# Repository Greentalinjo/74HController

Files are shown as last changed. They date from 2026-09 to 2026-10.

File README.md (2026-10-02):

<p align="center">
  74HC-ontroller logo
</p>

# 74HC-ontroller

**A game controller built entirely from discrete 74HC logic.** Eight keys, a
diode ROM for a character table, and a real 8-N-1 serial frame out of an RJ45
console port — no microcontroller, no FPGA, no firmware, nothing programmable
anywhere on the board.

## Preface

This project started as an idea for a novel, old-school game controller to
plug into a MikroTik RB4011 that I own and am turning into a gaming console.
The RB4011 already has what a console needs to hear a controller — a serial
console port on an RJ45 jack — so the controller only has to do one thing:
turn a button press into a character on that line.

The twist is *how*. Instead of a microcontroller running a few lines of code,
every step — watching the buttons, noticing a change, looking up the
character, and shifting it out bit by bit at 115200 baud — is done by
sixteen logic chips from the 74HC family, the kind you would find in a 1980s
computer, plus one RS-232 line driver. Change the character a button sends by
moving a diode.

| At a glance | |
|---|---|
| Keys | 5-way navigation cluster + 3 Cherry MX switches |
| Output | 8-N-1 serial, 115200 baud by default, as RS-232 on an RJ45 (Cisco console pinout) or 3.3 V TTL on a header |
| Logic | 16 × 74HC-series ICs + a MAX3232 RS-232 transceiver |
| Key map | an 8 × 7 diode ROM — 56 positions, a diode wherever a bit is 1 |
| Power | one AA cell, boosted to 3.3 V; ~1.3 mA, roughly four weeks of continuous use |
| Board | 150 × 60 mm, 6 layers, 1.6 mm |
| Case | 3D-printed, three colours, sliding battery door |

---

## Contents

1. [How it works — the big picture](#1-how-it-works--the-big-picture)
2. [The pipeline, stage by stage](#2-the-pipeline-stage-by-stage)
3. [Putting it together: the life of a key press](#3-putting-it-together-the-life-of-a-key-press)
4. [What you can configure](#4-what-you-can-configure)
5. [Using it with a MikroTik console](#5-using-it-with-a-mikrotik-console)
6. [The hardware](#6-the-hardware)
7. [The case](#7-the-case)
8. [Building one](#8-building-one)
9. [Repository layout](#9-repository-layout)

---

## 1. How it works — the big picture

A microcontroller would handle a key press with a loop and an interrupt. This
board does the same job as a small **pipeline of hardware stages**, each on
its own schematic sheet, each handing a signal to the next:

```mermaid
flowchart LR
    subgraph clock["Power, clock, reset"]
        P["AA cell → boost → 3.3 V"]
        C["crystal → 74HC4060 → baud tap<br/>CLK / nCLK"]
        R["power-on reset<br/>POR_n"]
    end

    K["8 keys<br/>RC + Schmitt debounce"] --> L["74HC151<br/>LIVE key"]
    S["74HC161<br/>scan counter"] -- "address" --> L
    S -- "address" --> M["74HC259<br/>state memory"]
    M --> T["74HC151<br/>STORED key"]
    S -- "address" --> T
    L --> X["74HC86<br/>DIFF = LIVE xor STORED"]
    T --> X
    X --> B["74HC74<br/>BUSY"]
    B -- "freeze" --> S
    B --> Q["74HC161 + 74HC138<br/>frame sequencer"]
    Q -- "state 10: store" --> M
    S -- "address" --> D["74HC238 + diode ROM<br/>the character"]
    D --> SR["2 × 74HC165<br/>shift register"]
    SR --> G["74HC32<br/>output gate"]
    G --> O["JP4: TTL header<br/>or MAX3232 → RJ45"]
```

The idea in one paragraph: a counter **scans** the eight keys one at a time,
comparing each key's **live** state with the state the board **remembers**.
When they differ, a key has changed. The board then **freezes the scan** on
that key, uses the key's number to select a row of the **diode ROM** — which
presents that key's character — **shifts** the character out as a serial
frame, **stores** the key's new state so the difference disappears, and
**resumes** scanning. Everything is clocked by the baud-rate clock, so the
whole machine runs in lock-step with the serial line.

---

## 2. The pipeline, stage by stage

The schematic is split into seven sheets, in the order a signal travels
through them. A PDF of the whole schematic is in
[`docs/schematic.pdf`](docs/schematic.pdf).

### Stage 1 — Power, clock and reset *(sheet: Power, Clock, Reset)*

Everything else depends on three things from this sheet.

**Power.** One AA cell goes through the power switch (SW10) into an
**ME2108A33 boost converter** (U18, with L1, D3 and C1), which makes the
board's single **3.3 V** rail. It starts from a 0.9 V cell and keeps
regulating down to 0.45 V, so the battery is used to the end. JP1 can instead
take power from the TTL header. D1 is the power LED.

**Clock.** A **3.6864 MHz crystal** drives the oscillator inside a
**74HC4060** (U1), which also divides the frequency by powers of two. Jumper
**JP2** picks one of those outputs as the bit clock, `CLK` — by default
3.6864 MHz ÷ 32 = exactly **115200 Hz**, one tick per serial bit. A Schmitt
inverter makes `nCLK`, its opposite edge, which the control logic uses.

**Reset.** An RC network (R6, C5) and two Schmitt inverters hold `POR_n` low
for about 87 ms at switch-on, which clears the state memory, the scanner and
the BUSY flag — so the controller never sends a burst of junk characters when
it powers up. SW9 is a manual reset button.

### Stage 2 — Keys and debounce *(sheet: Keys and Debounce)*

Each of the eight keys has its own complete **debounce cell**: a 10 kΩ
pull-up, a 1 kΩ series resistor, a 1 µF capacitor to ground and a **74HC14
Schmitt-trigger** inverter.

```
+3V3 ──[10k]──┬──[1k]── switch ── GND
              │
             1µF          ──► 74HC14 ──► KEYn  (high while pressed)
              │
             GND
```

The cell is deliberately **asymmetric**: pressing discharges the capacitor
through 1 kΩ (a ~1.7 ms response), releasing recharges it through 10 kΩ
(~7.4 ms). The slow edges swallow contact bounce, and the Schmitt trigger
turns the slow analogue ramp into one clean logic edge.

The keys are **KEY0–KEY4**: the five directions of an SJMS 5-way navigation
cluster (SW1, one package) — **KEY5–KEY7**: three Cherry MX switches (SW6–SW8).

### Stage 3 — Scanner and memory *(sheet: Scanner and Memory)*

This stage decides *whether* anything needs sending.

* A **74HC161 counter** (U4) steps a 3-bit address, `ADDR0–2`, through the
  eight keys, one key per clock tick. A full sweep takes eight bit times.
* A **74HC151 multiplexer** (U5) reads the addressed key's live state: `LIVE`.
* A **74HC259 addressable latch** (U6) is the board's memory — eight bits
  holding the last state that was *reported* for each key.
* A second **74HC151** (U7) reads the remembered state of the same key:
  `STORED`. (The '259 has no read-back port of its own, so this second
  multiplexer is essential.)
* A **74HC86 XOR** gate compares the two: `DIFF = LIVE xor STORED`.

`DIFF` goes high exactly when the key under the scanner has changed since it
was last reported. That is the only event this whole machine reacts to.

### Stage 4 — Transmit sequencer *(sheet: Transmit Sequencer)*

This stage runs a transmission once `DIFF` says there is something to send.

* **`BUSY`** — a 74HC74 flip-flop (U9A) captures `DIFF` on the `nCLK` edge.
  While `BUSY` is high, the scan counter is **frozen** through its count
  enables. The clock itself is never gated, so there are no glitches.
* A second **74HC161** (U10) counts the bit times of the frame, and a
  **74HC138** decoder (U11) picks out two moments from that count:
  * **State 10** — the frame has finished, so it pulses the 74HC259's write
    enable. The key's new state is stored, `DIFF` falls, and on the next edge
    `BUSY` clears itself and the scanner moves on.
  * **State 11** — a lock-up escape. If `DIFF` somehow failed to clear, the
    second flip-flop (U9B) forces `BUSY` off, so the controller can never
    freeze for good.

The whole event takes **11 bit times**: 10 for the frame, 1 to store and
resume. That's about 95 µs at 115200 baud.

### Stage 5 — ASCII diode ROM *(sheet: ASCII Diode ROM)*

This stage decides *what* gets sent. It is a real read-only memory, built
from diodes:

* A **74HC238 decoder** (U14) takes the frozen key address and drives exactly
  one of eight **rows** high — one row per key.
* Seven **columns** run across the rows, one per bit of the ASCII code
  (b0–b6), each held low by a 15 kΩ pull-down (R30–R36).
* Where a bit should be 1, a **diode** connects that key's row to that bit's
  column (anode to the row, cathode to the column). Driving the row pulls
  those columns high; the rest stay low.

Of the 56 positions (8 keys × 7 bits), **27 are fitted** for the default key
map. The decoder is only enabled while `DIFF` is high, so the ROM draws
nothing at rest.

### Stage 6 — UART shift register *(sheet: UART Shift Register)*

Two **74HC165 shift registers** (U15, U16) are chained into a 16-bit
register that holds the whole frame:

| Frame bit | Comes from |
|---|---|
| start (0) | tied to ground |
| b0 … b6 | the ROM columns |
| bit 7 | make/break flag (see §4) |
| stop (1) | tied to 3.3 V |
| idle (1s) | tied to 3.3 V |

While the board is idle, `BUSY` holds the registers in **parallel load**, so
the start bit is already waiting on the output. The instant `BUSY` rises they
start shifting — one bit per `nCLK` — which produces the serial frame
directly, least-significant bit first.

A **74HC32 OR gate** (U13) then forms the final line:
`TX = shift register OR not-BUSY OR SUPPRESS`. `not-BUSY` parks the line high
(idle) between frames, and `SUPPRESS` blanks a key-*release* frame when break
codes are turned off.

### Stage 7 — Output *(sheet: Output Stage)*

The finished 3.3 V serial line goes to **JP4**, which sends it one of two ways:

* **RS-232** — through a **MAX3232** (U17) to the **RJ45** console jack, using
  the Cisco console pinout that MikroTik and most network gear use.
* **3.3 V TTL** — to the 4-pin header **J3**, for a USB-serial adapter or
  another board.

The MAX3232's spare receiver also converts the *other* direction: whatever
the connected device prints on its console comes back as 3.3 V TTL on J3 pin
3, so you can watch the console while the controller drives it.

---

## 3. Putting it together: the life of a key press

Everything is timed in **bit times** (one `CLK` period: 8.7 µs at 115200
baud). The control logic acts on `nCLK`, half a bit away from the scanner's
`CLK`, so the scan address is always settled before anything reads it.

| When | What happens |
|---|---|
| — | You press a key. The debounce cell settles, and `KEYn` goes high about 1.7 ms later. |
| within 8 bit times | The scanner reaches that key. `LIVE` = 1, `STORED` = 0, so **`DIFF` = 1**. |
| f0 | `BUSY` rises on `nCLK`. The scanner **freezes**, the ROM row for this key is driven, and the shift registers start sending — the **start bit** is already on the line. |
| f1 – f7 | ASCII bits **b0 … b6**, straight from the diode ROM. |
| f8 | **bit 7** (0 unless make/break codes are on). |
| f9 | **stop bit**. |
| f10 | Sequencer state 10: the new key state is **written into memory**. `DIFF` falls. |
| f11 | `BUSY` clears itself. The scanner **resumes**. |

Releasing the key is the same event in reverse: the key now differs from
memory again, so another frame is sent, or quietly suppressed if break codes
are off.

Because each change is handled on its own sweep, pressing all eight keys at
once produces eight clean frames back to back (8.8 ms at 9600 baud, under
1 ms at 115200). Nothing is lost and nothing is merged, since only one key
can be transmitting at a time.

---

## 4. What you can configure

Everything is set with jumpers, solder bridges and diodes. There's no
firmware to reflash.

### Jumpers at a glance

| Ref | What it sets | Options | Default |
|---|---|---|---|
| **JP1** | Power source | 1-2 AA cell via the boost converter · 2-3 from TTL header J3 pin 4 | 1-2 |
| **JP2** | Baud rate | one shunt across one of seven columns (below) | column 2 = 115200 |
| **JP3** | Break codes | open = press only · fitted = press *and* release | open |
| **JP4** | Output | 1-2 RS-232 on the RJ45 · 2-3 3.3 V TTL on J3 | 2-3 |
| **JP5** | Both outputs | solder bridge: drive RS-232 *and* TTL at once | open |
| **JP6 / JP7** | RJ45 cable type | both 2-3 straight patch cable · both 1-2 rollover console cable | 2-3 |
| **JP8 / JP9** | Handshake | solder bridges that assert DSR / CTS, for devices that insist | open |

### Baud rate — JP2 and the crystal

JP2 picks a divider tap from the 74HC4060. Its seven columns follow the
chip's pin order, **not** baud order. That keeps the wiring uncrossed, and a
table on sheet 2 of the schematic maps them.

| JP2 column | 1 | 2 | 3 | 4 | 5 | 6 | 7 |
|---|---|---|---|---|---|---|---|
| '4060 tap | Q6 ÷64 | Q5 ÷32 | Q7 ÷128 | Q4 ÷16 | Q10 ÷1024 | Q8 ÷256 | Q9 ÷512 |
| **3.6864 MHz** (fitted) | 57600 | **115200** | 28800 | 230400 | 3600 | 14400 | 7200 |
| 4.9152 MHz | 76800 | 153600 | 38400 | 307200 | 4800 | 19200 | **9600** |

115200 and 9600 differ by a factor of 12, not a power of two, so no single
crystal reaches both. For a 9600-baud controller, fit a 4.9152 MHz crystal
and use column 7.

### The key map — moving diodes

Each key sends the 7-bit ASCII code wired into its row of the ROM. The diode
for **key *k*, bit *b*** is **D2*kb***. For example, D245 is key 4, bit 5.
Fit a diode wherever the bit should be 1.

| Key | Button | Sends | Code | Diodes fitted |
|---|---|---|---|---|
| 0 | nav centre / OK | Enter (CR) | 0x0D | D200 D202 D203 |
| 1 | nav up | Tab | 0x09 | D210 D213 |
| 2 | nav down | Esc | 0x1B | D220 D221 D223 D224 |
| 3 | nav left | Ctrl-C | 0x03 | D230 D231 |
| 4 | nav right | `/` | 0x2F | D240 D241 D242 D243 D245 |
| 5 | MX 1 | `?` | 0x3F | D250 D251 D252 D253 D254 D255 |
| 6 | MX 2 | Space | 0x20 | D265 |
| 7 | MX 3 | `q` | 0x71 | D270 D274 D275 D276 |

The silkscreen labels the grid like a table, since 56 designators would not
fit. Across the top is `D20 21 22 … 27`, one label per key column. Down the
right side is `0`–`6`, one per bit, next to that bit's pull-down R30–R36. A
diode's designator is the label above it followed by the digit beside it.

### Press-only or make/break — JP3

* **Open (default):** a key sends its character when pressed and nothing on
  release. This is plain typing, the right choice for a console.
* **Fitted:** a press sends `0x80 | code` and a release sends `code`. Bit 7
  carries the key's state, which gives a game true key-down/key-up events.

### Output — JP4, JP5, JP6/JP7, JP8/JP9

* **JP4** chooses RS-232 on the RJ45 or 3.3 V TTL on J3. The unused output is
  held at its idle level, not left floating.
* **JP5** drives both outputs at once.
* **JP6/JP7** move the transmit and receive lines between RJ45 pins 3 and 6,
  so both a straight patch cable and a rollover console cable work. Always
  move them together.
* **JP8/JP9** assert DSR and CTS from a spare driver. RouterOS doesn't need
  them.

**J3 (TTL header):** 1 GND · 2 TXD out · 3 RXD (the far end's console, as
3.3 V TTL) · 4 +3.3 V, in or out depending on JP1.

### Other options

* **Power LED:** leave D1 and R3 off to save 0.28 mA, about a quarter of the
  idle current.
* **R53** stays unfitted. It belonged to a 5 V version of the design and
  would now pull the TTL output below a 3.3 V input's threshold.

---

## 5. Using it with a MikroTik console

1. Set **JP4 to 1-2** (RS-232), and leave JP6/JP7 on 2-3.
2. Connect the controller's RJ45 to the router's **Serial** console port with
   an ordinary straight Ethernet patch cable.
3. The console runs at **115200 8-N-1**, which is JP2's default. RouterBOOT's
   console rate can't be changed, which is why the controller runs at
   115200 rather than 9600.
4. Switch on. Every key press arrives on the console as a plain keystroke,
   ready for whatever is reading it.

For a PC instead, set JP4 to 2-3 and plug a 3.3 V USB-serial adapter into
J3.

---

## 6. The hardware

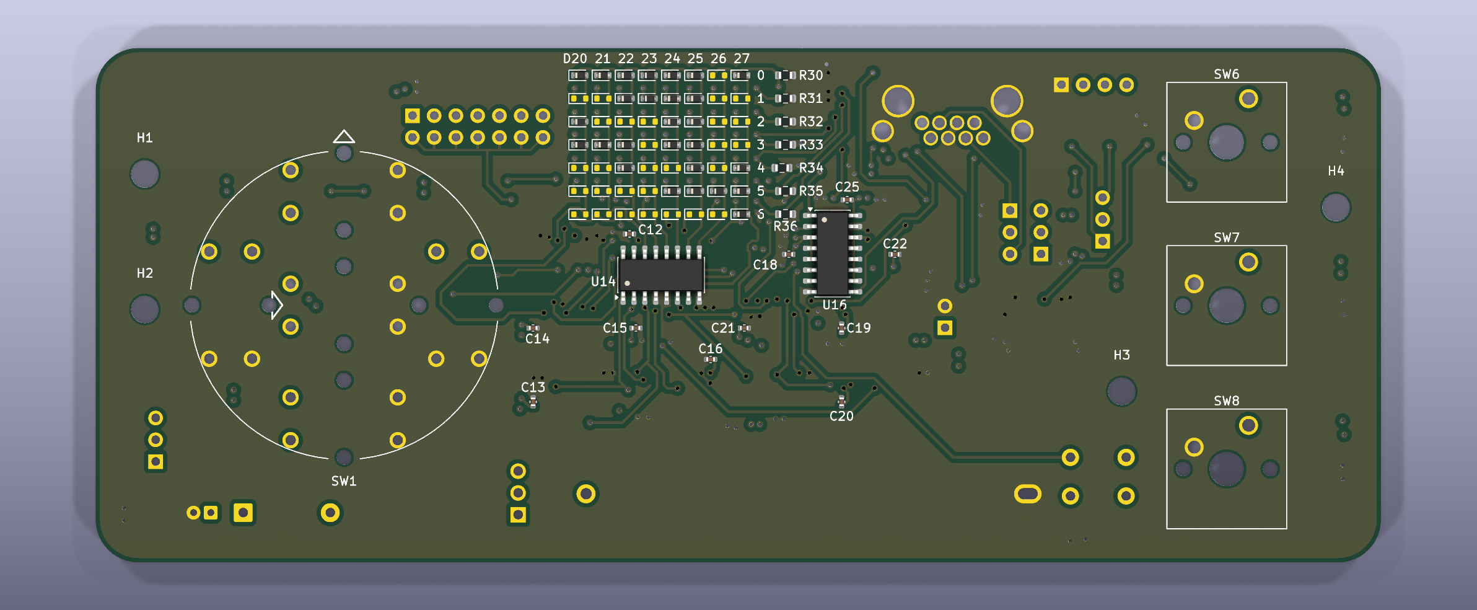
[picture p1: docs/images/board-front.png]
Board front

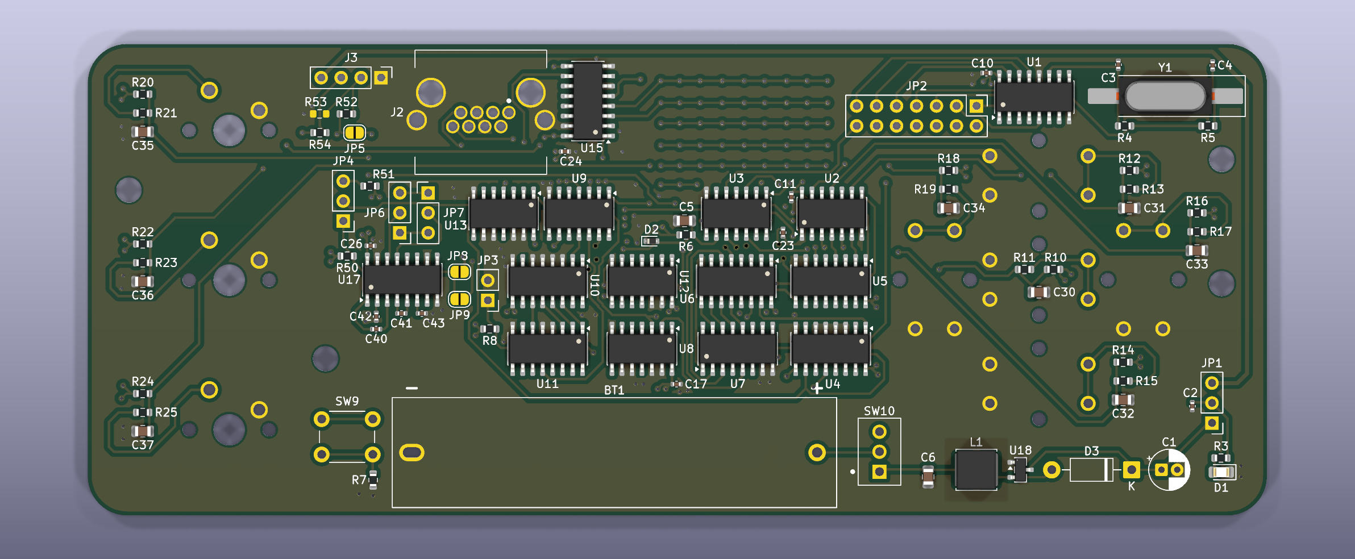
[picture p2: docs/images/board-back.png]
Board back


* **150 × 60 mm, 6-layer, 1.6 mm.** Signals run on the outer layers. Ground
  is poured on the top, bottom and three inner layers, and the 3.3 V supply
  has its own inner plane.
* **Front:** the navigation cluster, the three MX switches, the diode ROM and
  its decoder and pull-downs, one of the shift registers and some decoupling.
* **Back:** the rest of the logic, the RJ45, the TTL and jumper headers, the
  power switch, the reset button and the AA holder.
* **Parts:** all logic in SOIC. Passives are 0603/0402, with 0805 for the 1 µF
  debounce capacitors, and the ROM diodes are SOD-523. Through-hole parts are
  used only where needed: switches, connectors, headers, the AA holder, C1
  and D3.
* **Four M3 mounting holes** (H1–H4) take the case screws.

Three parts have requirements the footprint alone doesn't capture:

* **C30–C37 and C5 (1 µF) must be 0805 X7R.** A 1 µF 0402 part loses so much
  capacitance under DC bias that the debounce timing guarantee breaks at
  9600 baud.
* **C3/C4 (30 pF crystal load) must be C0G/NP0**, to keep the oscillator
  stable and starting reliably.
* **U17 must be a MAX3232** (or MAX232A/SP3232), not a plain MAX232, which
  needs 1 µF pump capacitors. The logic must be **74HC**, not 74HCT or 74LS.

### How it was checked

Before any copper was ordered, the design's netlist was run in a purpose-built
logic simulator that models every IC against its datasheet truth table.
Switches were driven through the real RC debounce values, and the serial
output was decoded like a real UART receiver. The runs covered:
* 108 scenarios, including every key, eight keys at once, bounce, make/break,
  both outputs and a deliberate lock-up;
* 1,268 randomised and exhaustive assertions, including all 255 key
  combinations;
* a DC noise-margin check of every logic level at 3.3 V.

The simulator isn't part of this repository. The schematic passes KiCad ERC
with no errors, and the board passes DRC and matches the schematic.

---

## 7. The case

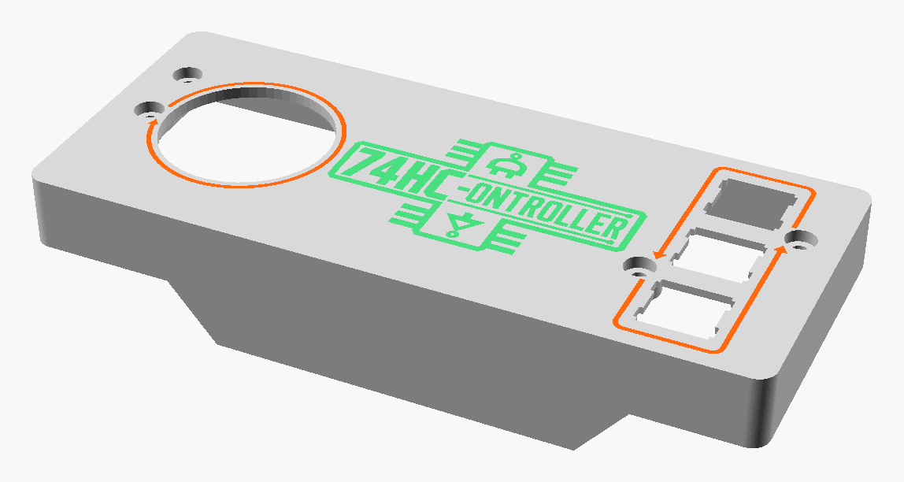
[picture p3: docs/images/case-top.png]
Case top, with the three-colour inlay


A three-piece 3D-printed enclosure, ready to slice, in [`case/`](case/):

| File | Part | Print |
|---|---|---|
| `top_with_trim.3mf` | top shell, holding the switches | three colours: plate, trim and logo inlays. Print plate side down, no supports |
| `bottom.3mf` | bottom shell | print on its raised hump. Support only the flat undersides (grid supports, build plate only, 2–3 interface layers, a brim) |
| `door.3mf` | battery door | outer face down, no supports |

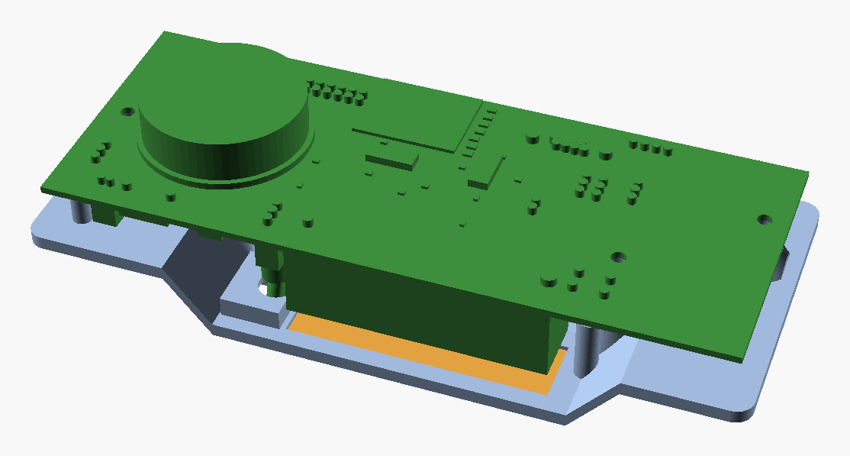
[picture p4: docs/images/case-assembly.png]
Opened assembly


The case is shaped to be held in both hands from the ends. The bottom steps
down only where the tall parts are (the battery, power switch and RJ45) and
slopes up everywhere else. It has:
* windows over every jumper header;
* a pinhole for the reset button;
* a pocket for the power switch lever;
* a small light hole for the power LED;
* an RJ45 opening in the top wall.

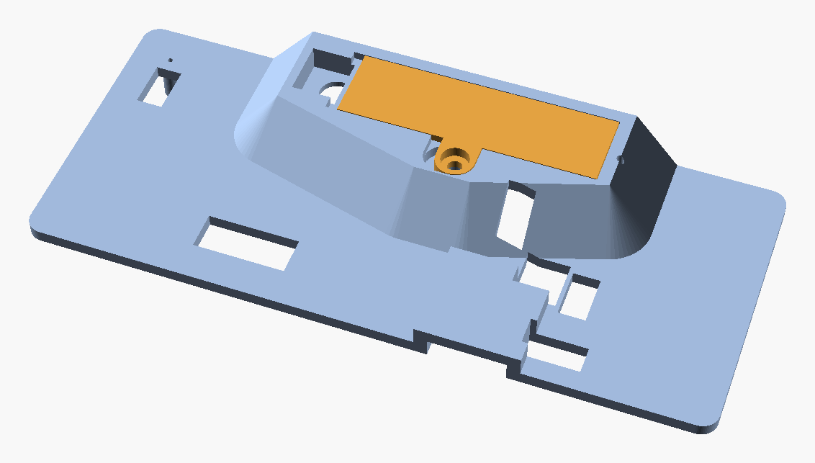
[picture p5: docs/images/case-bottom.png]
Bottom shell


**Hardware:** five **M3 × 8 pan-head screws** and five **M3 heat-set
inserts**, which go in 4.2 mm holes up to 8 mm deep.

**Assembly:**
1. Clip the switches into the top plate and solder the PCB to them.
2. Press heat-set inserts into the tops of the bottom shell's four posts, and
   the fifth into the battery door's screw boss, from underneath.
3. Close the bottom and drive four screws down through the counterbored holes
   in the top, so the heads sit flush, through the PCB and into the inserts.
4. Drop the battery door into its seat, slide it right so its tongues go
   under the lip, and fix it with the fifth screw.

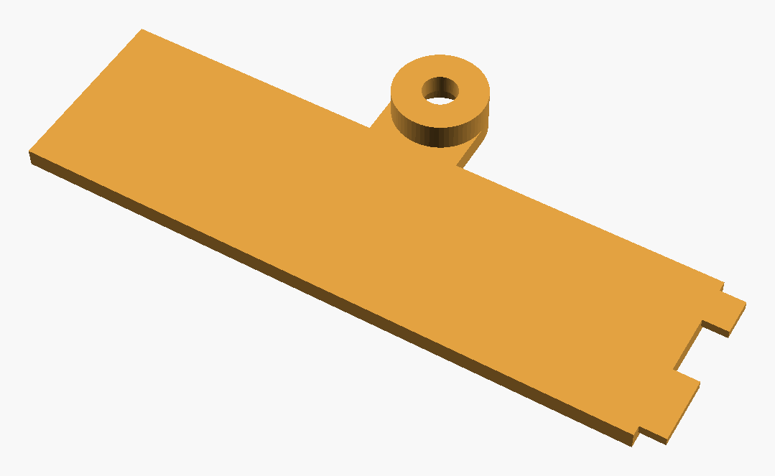
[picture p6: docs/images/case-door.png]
Battery door


---

## 8. Building one

1. **The PCB.** Open `kicad/logic-macropad.kicad_pro` in **KiCad 10** or newer
   and plot gerbers and drill files. The project is self-contained, with its
   own symbol and footprint libraries. Order 6 layers, 1.6 mm, FR-4. Nothing
   on the board is impedance-sensitive, so any standard stackup works.
2. **The parts.** Every symbol carries its specification and an example part
   number in its fields. *Tools → Generate BOM* in the schematic editor, or
   `kicad-cli sch export bom`, lists them. The 29 unused ROM positions and
   R53 are marked *do not populate*.
3. **Assembly.** Everything is hand-solderable, but the SOD-523 ROM diodes are
   small. Fit only the diodes for your key map (§4). Set the jumpers, fit an
   AA cell, and switch on.

---

## 9. Repository layout

```
kicad/                          the KiCad 10 project
  logic-macropad.kicad_pro        project, design rules
  logic-macropad.kicad_sch        root sheet: block diagram, the seven stages
  01_power_clock.kicad_sch        stage 1  power, clock, reset
  02_keys_debounce.kicad_sch      stage 2  keys and debounce
  03_scanner.kicad_sch            stage 3  scanner and memory
  04_sequencer.kicad_sch          stage 4  transmit sequencer
  05_ascii_rom.kicad_sch          stage 5  ASCII diode ROM
  06_uart_tx.kicad_sch            stage 6  UART shift register
  07_output.kicad_sch             stage 7  output stage
  logic-macropad.kicad_pcb        the 6-layer board
  lib/, logic-macropad.pretty/    project symbols and footprints
case/                           print-ready 3MF files for the enclosure
docs/
  schematic.pdf                   the full schematic
  images/                         renders used in this README
```

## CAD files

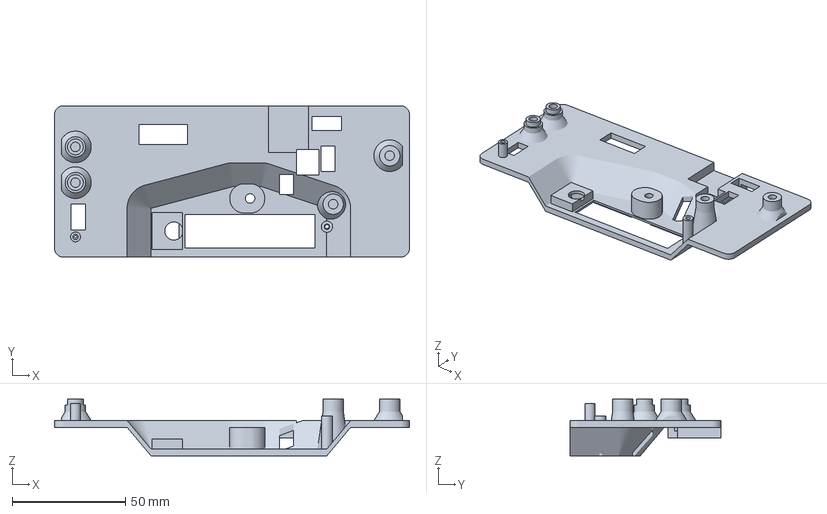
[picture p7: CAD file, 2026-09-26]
case/bottom.3mf
157.0 x 67.0 x 25.1 mm

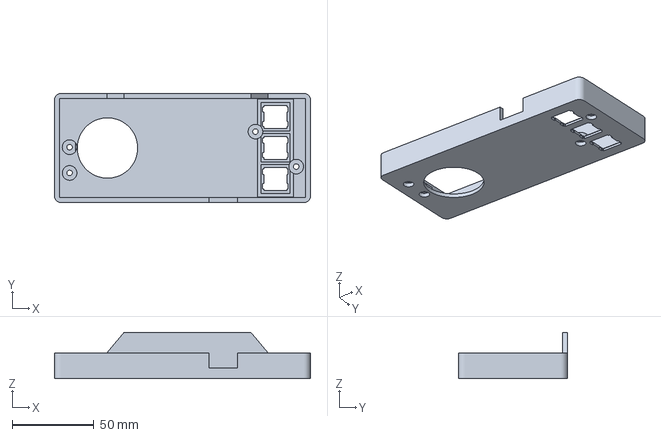
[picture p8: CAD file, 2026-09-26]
case/top_with_trim.3mf
157.0 x 67.0 x 28.5 mm

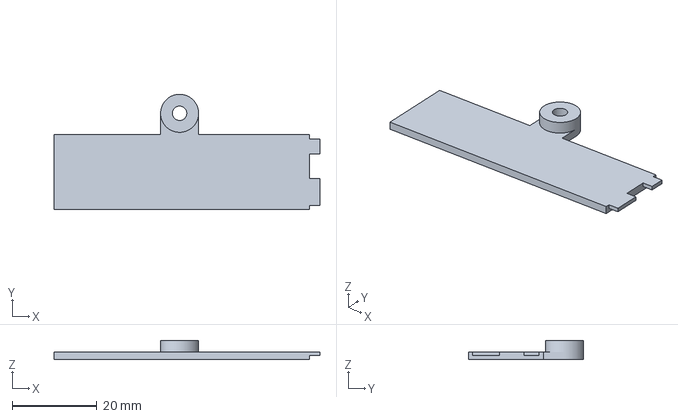
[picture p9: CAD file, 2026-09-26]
case/door.3mf
62.9 x 27.3 x 4.50 mm

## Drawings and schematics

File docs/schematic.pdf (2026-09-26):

1 | 2 | 3 | 4 | 5 | 6 | 7 | 8

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
Size: A3 | Rev: A | F Date: 2026-09-04
KiCad E.D.A. 10.0.1 | Id: 1/8

## Title: Logic Macropad - Root / block diagram

File: logic-macropad.kicad_sch

Sheet: /

8-key macropad, 74HC logic only, no MCU/FPGA

Selectable TTL UART or RS-232 output

Output Stage

File: 07_output.kicad_sch

Keys and Debounce

File: 02_keys_debounce.kicad_sch

ASCII Diode ROM

File: 05_ascii_rom.kicad_sch

Power, Clock, Reset

File: 01_power_clock.kicad_sch

UART Shift Register

File: 06_uart_tx.kicad_sch

Scanner and Memory

File: 03_scanner.kicad_sch

Transmit Sequencer

File: 04_sequencer.kicad_sch

#FLG02 PWR_FLAG

#FLG01 PWR_FLAG +3V3 | GND

PWR_FLAGs: tell ERC that +3V3 / GND are driven.

8-key keypad that emits a real 8-N-1 serial frame per key event, built only from 74HC glue logic and a diode ROM. No MCU, no FPGA, no firmware, no programmable part of any kind.

### PRINCIPLE OF OPERATION

A 74HC161 sweeps a 3-bit address across the 8 keys at the bit clock, so every key is sampled 1/8 of the baud rate (1200 Hz at 9600 baud).

### 74HC151 #1 reads the LIVE debounced key at that address; 74HC151 #2

reads the STORED state of the same address out of a 74HC259 latch.

### A 74HC86 XORs them. A difference sets the BUSY flip-flop on the

FALLING clock edge, which freezes the scan counter through its synchronous count-enables (CEP/CET) - the clock itself is never gated, so no runt pulses are possible.

While BUSY, the frozen address selects one row of a 74HC238 +
diode ROM, which presents 7 ASCII bits to a pair of 74HC165s.
The shift registers emit start / b0..b6 / make-break / stop over
the next 10 bit times. A second 74HC161 + 74HC138 count the frame,
write the new key state into the 74HC259 at state 10, and release BUSY one bit later. Scanning resumes; N-key rollover falls out for free because each pending change is serviced on a later sweep.
OUTPUT | JP4 selects 3.3V TTL UART or RS-232 (MAX3232 -> RJ45).
BAUD | JP2 taps the 74HC4060 divider; see sheet 2 for the table.
ASCII MAP | Set by which diodes are fitted; see sheet 6.

# DISCRETE LOGIC SERIAL MACROPAD

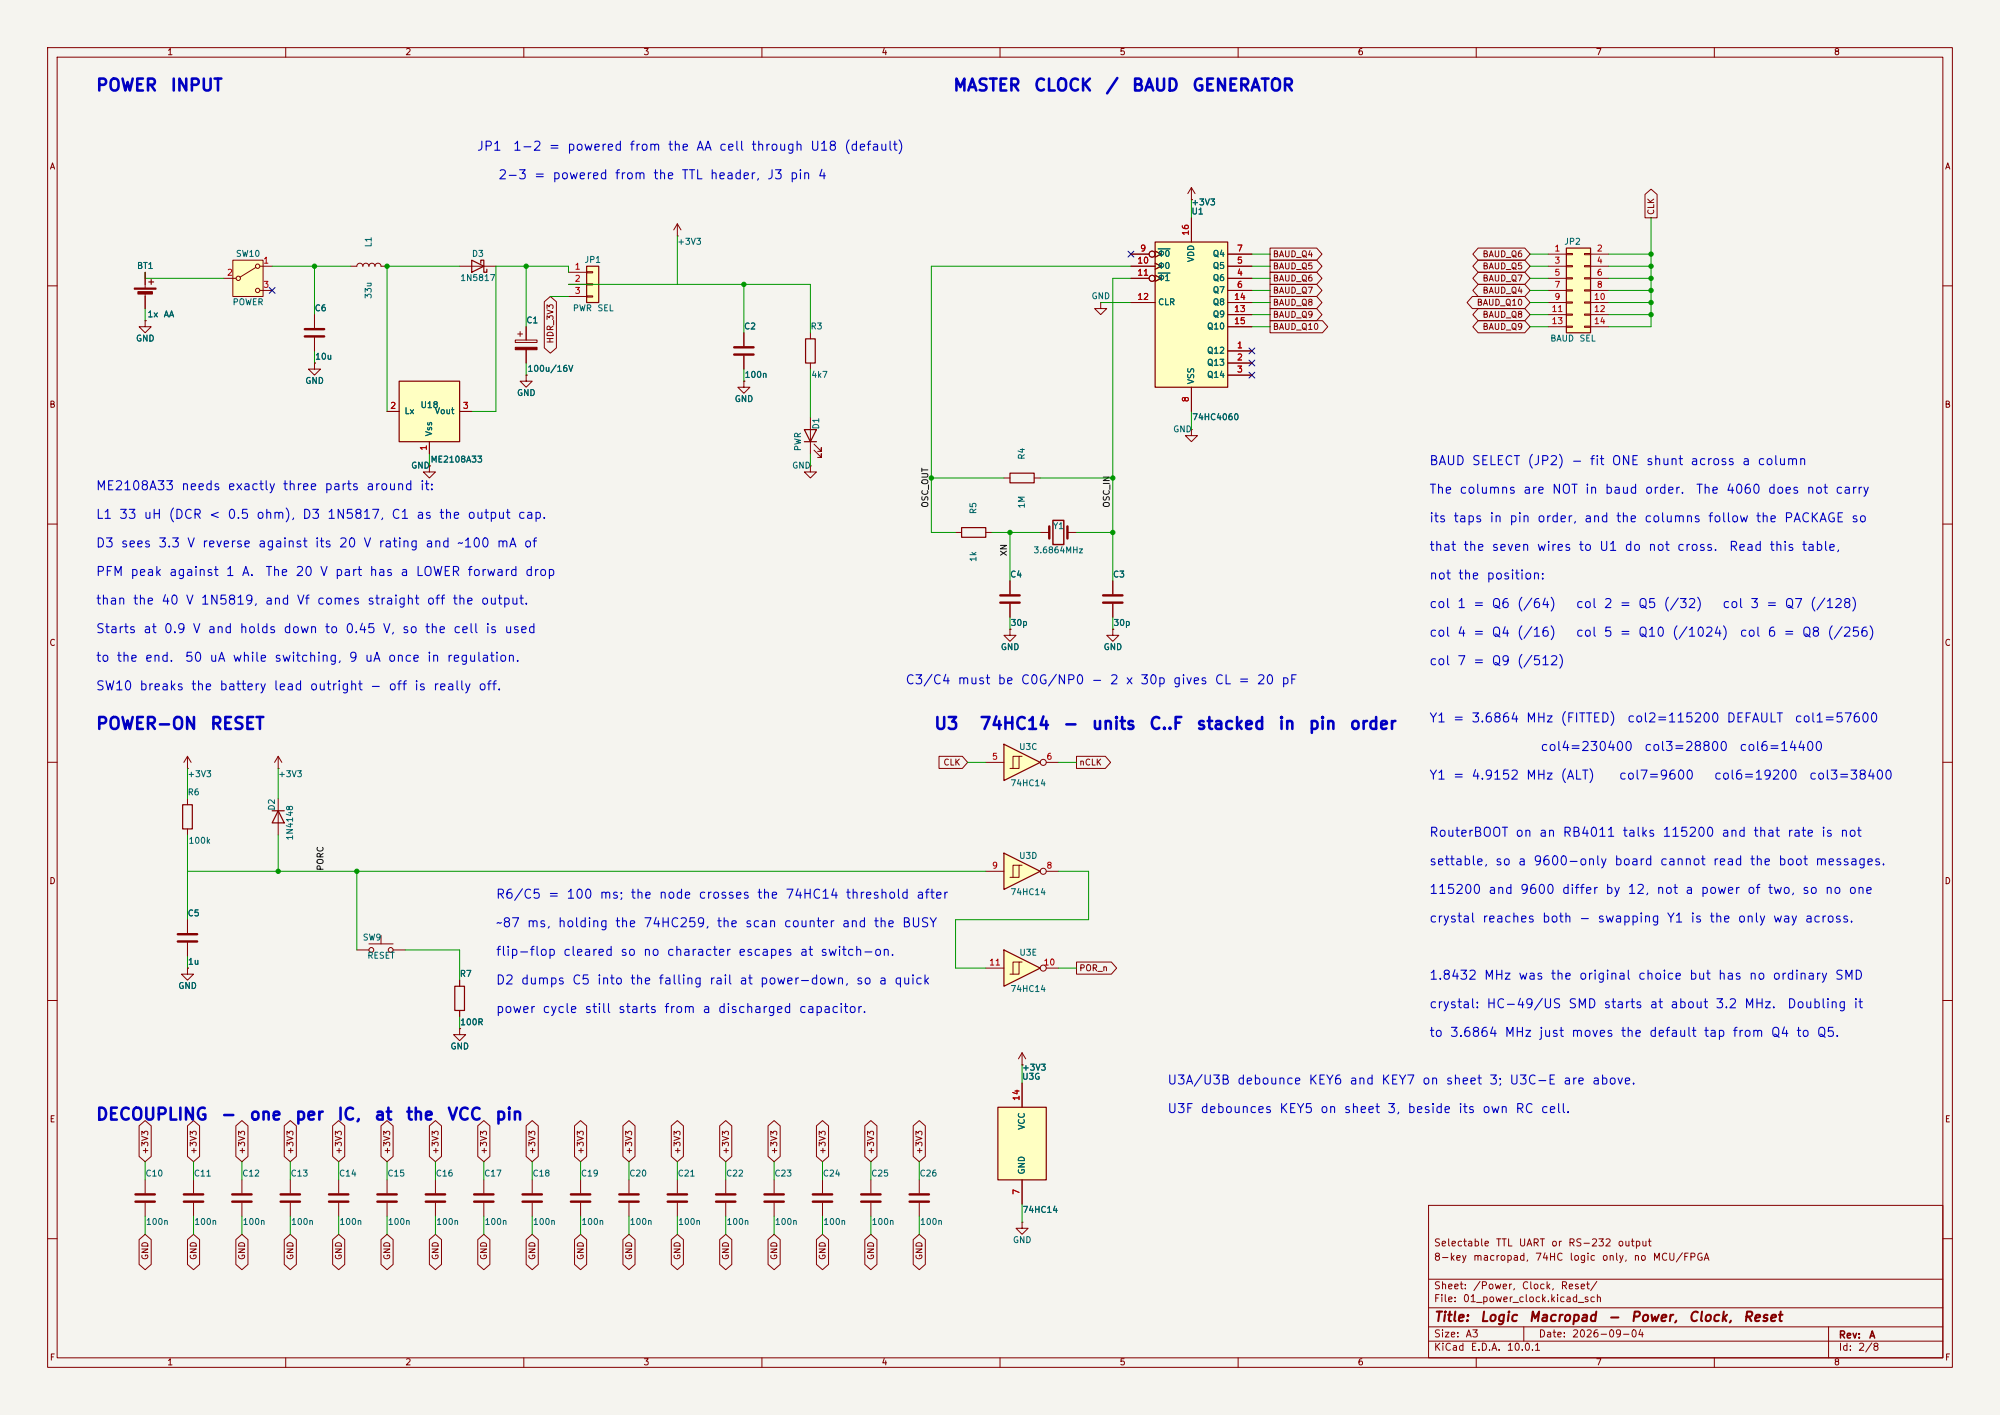
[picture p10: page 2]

MASTER CLOCK / BAUD GENERATOR

JP1 1-2 = powered from the AA cell through U18 (default)

2-3 = powered from the TTL header, J3 pin 4

BAUD SELECT (JP2) - fit ONE shunt across a column

L1 33 uH (DCR < 0.5 ohm), D3 1N5817, C1 as the output cap.
its taps in pin order, and the columns follow the PACKAGE so Starts at 0.9 V and holds down to 0.45 V, so the cell is used

D3 sees 3.3 V reverse against its 20 V rating and ~100 mA of

that the seven wires to U1 do not cross. Read this table,

PFM peak against 1 A. The 20 V part has a LOWER forward drop

than the 40 V 1N5819, and Vf comes straight off the output.

to the end. 50 uA while switching, 9 uA once in regulation.

C3/C4 must be C0G/NP0 - 2 x 30p gives CL = 20 pF

SW10 breaks the battery lead outright - off is really off.

U3 74HC14 - units C..F stacked in pin order

RouterBOOT on an RB4011 talks 115200 and that rate is not

settable, so a 9600-only board cannot read the boot messages.

R6/C5 = 100 ms; the node crosses the 74HC14 threshold after

115200 and 9600 differ by 12, not a power of two, so no one

~87 ms, holding the 74HC259, the scan counter and the BUSY

crystal reaches both - swapping Y1 is the only way across. 1.8432 MHz was the original choice but has no ordinary SMD

flip-flop cleared so no character escapes at switch-on.

D2 dumps C5 into the falling rail at power-down, so a quick

crystal: HC-49/US SMD starts at about 3.2 MHz. Doubling it

power cycle still starts from a discharged capacitor.

to 3.6864 MHz just moves the default tap from Q4 to Q5.

U3A/U3B debounce KEY6 and KEY7 on sheet 3; U3C-E are above.

8-key macropad, 74HC logic only, no MCU/FPGA

Sheet: /Power, Clock, Reset/
File: 01_power_clock.kicad_sch
Title: Logic Macropad - Power, Clock, Reset

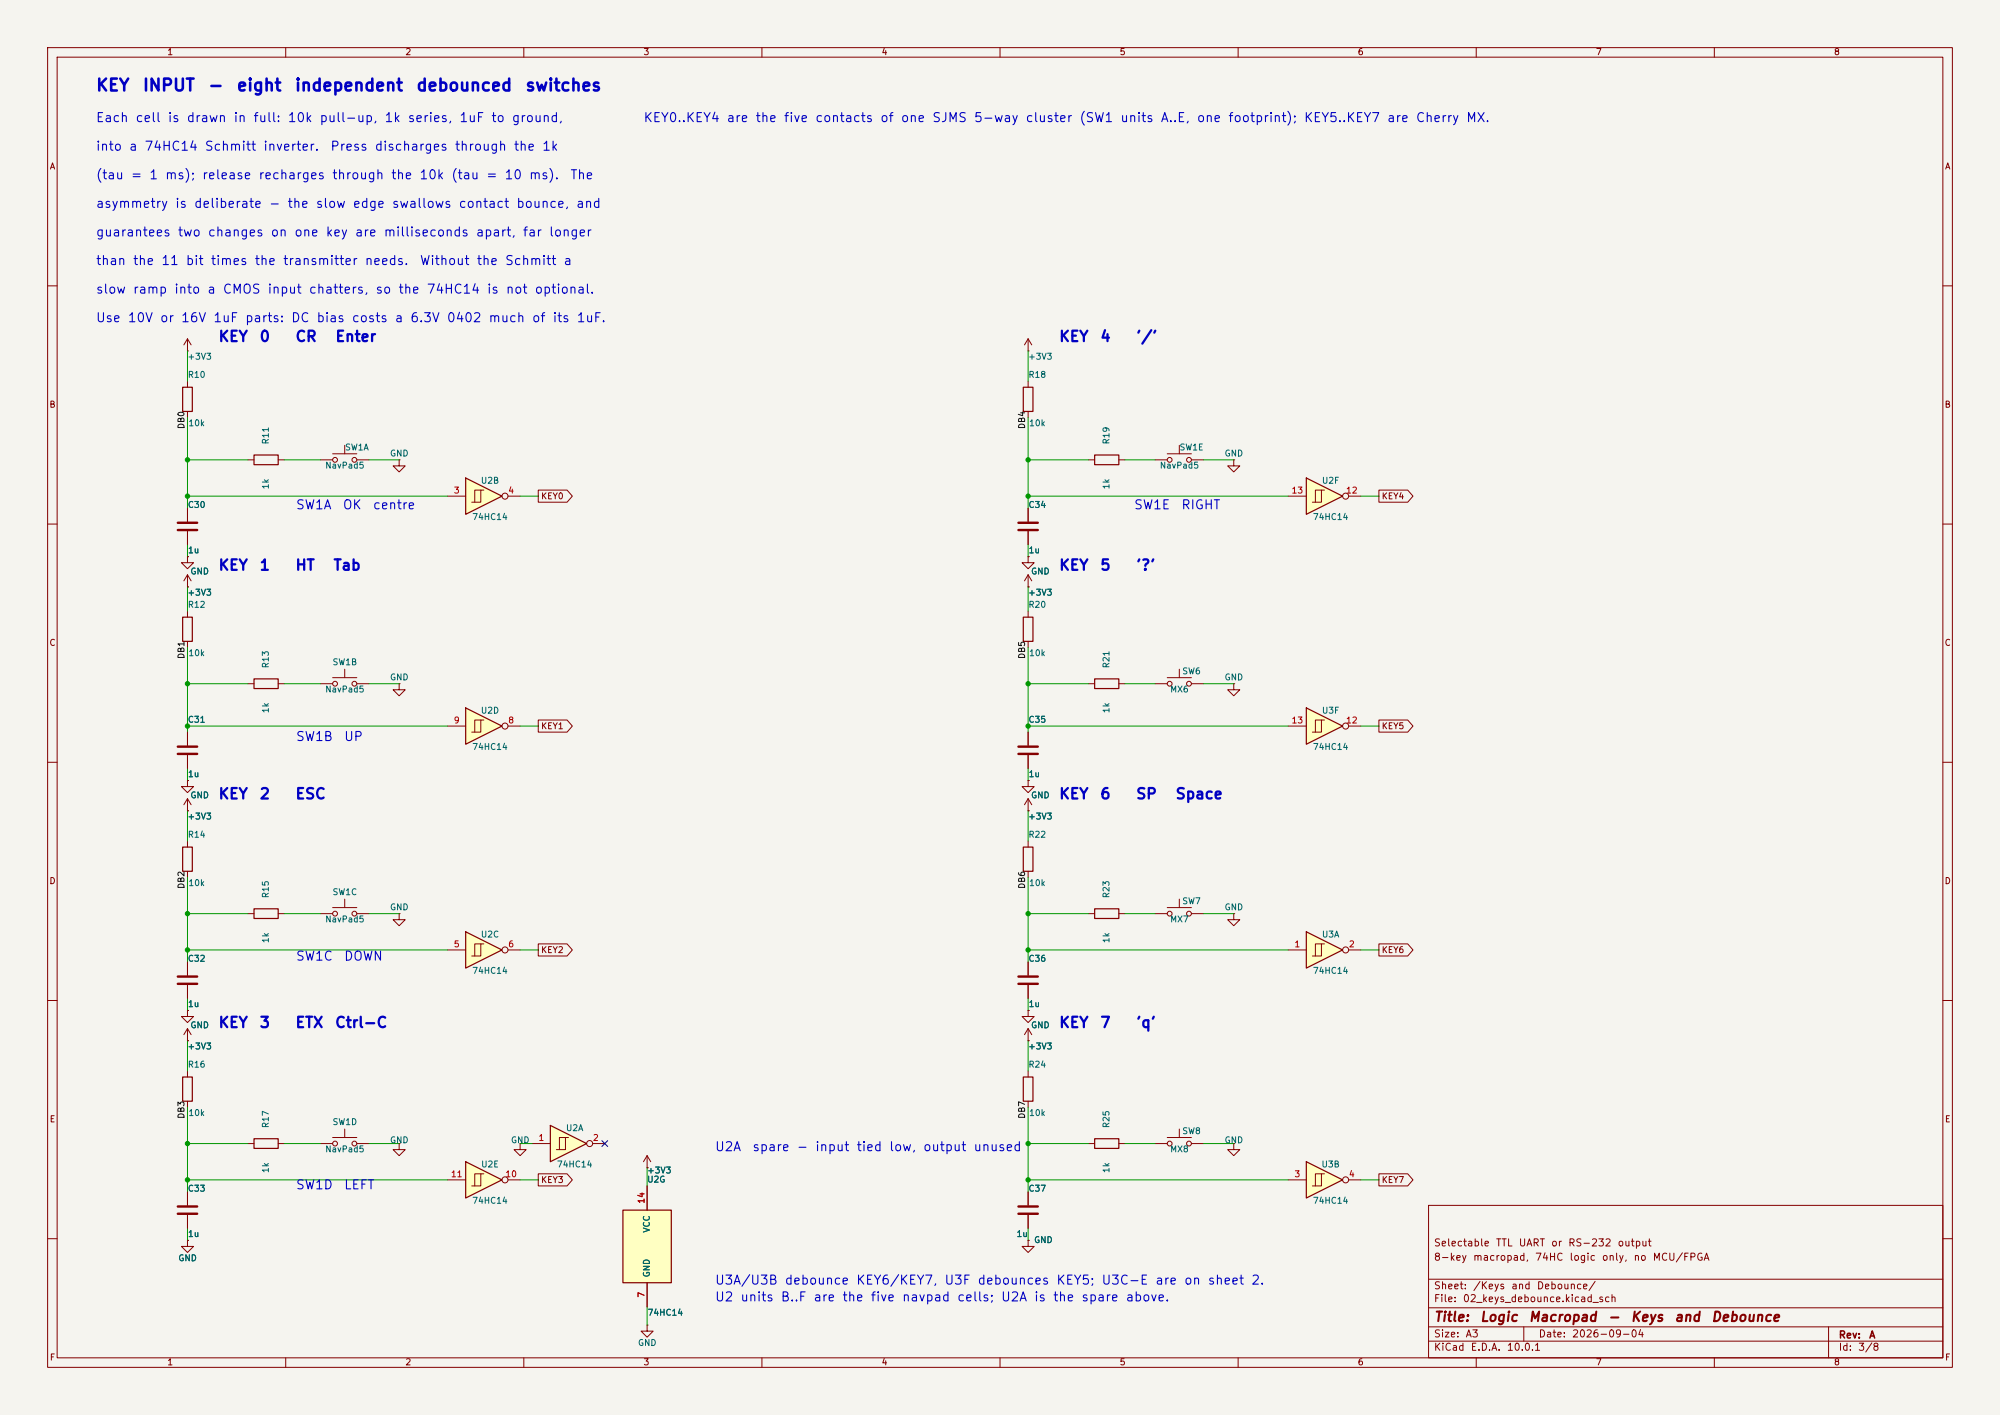
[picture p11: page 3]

KEY INPUT - eight independent debounced switches

Each cell is drawn in full: 10k pull-up, 1k series, 1uF to ground,

KEY0..KEY4 are the five contacts of one SJMS 5-way cluster (SW1 units A..E, one footprint); KEY5..KEY7 are Cherry MX.

into a 74HC14 Schmitt inverter. Press discharges through the 1k

(tau = 1 ms); release recharges through the 10k (tau = 10 ms). The

asymmetry is deliberate - the slow edge swallows contact bounce, and

guarantees two changes on one key are milliseconds apart, far longer
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

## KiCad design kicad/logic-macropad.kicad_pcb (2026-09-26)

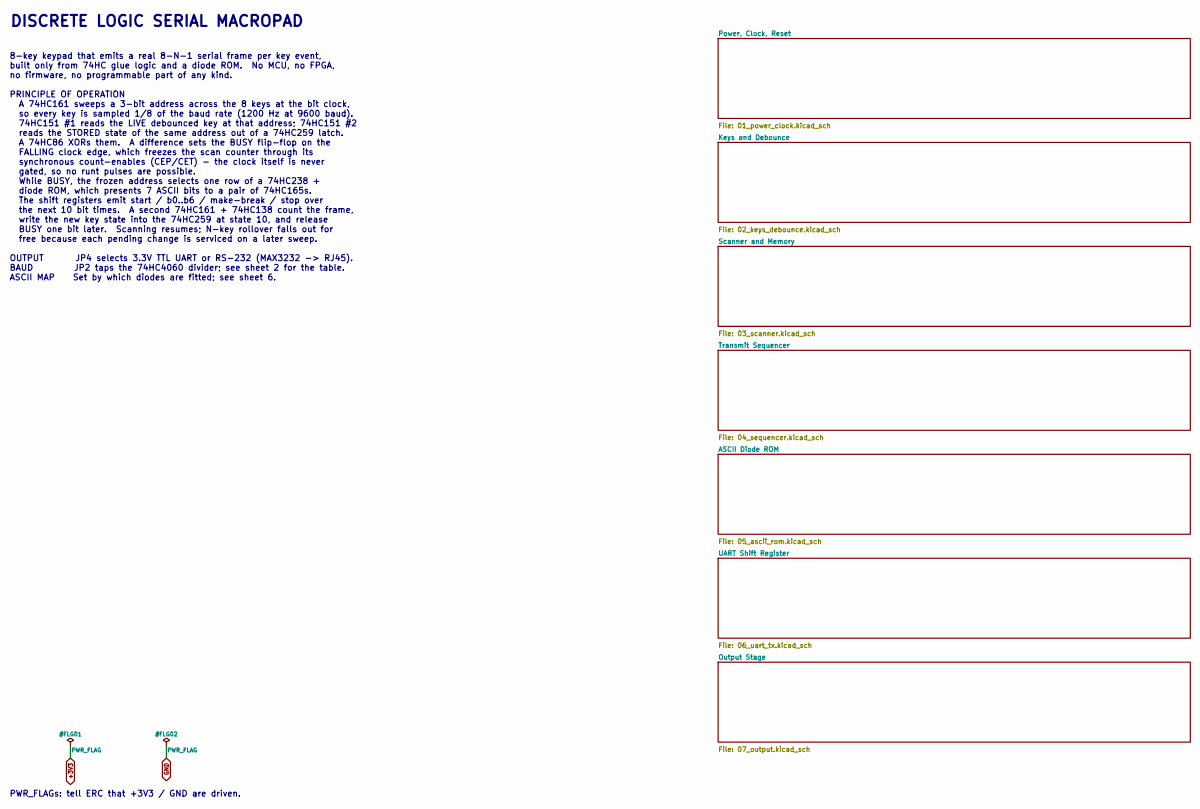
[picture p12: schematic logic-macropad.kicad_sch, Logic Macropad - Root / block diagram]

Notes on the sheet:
8-key keypad that emits a real 8-N-1 serial frame per key event, built only from 74HC glue logic and a diode ROM. No MCU, no FPGA, no firmware, no programmable part of any kind. PRINCIPLE OF OPERATION A 74HC161 sweeps a 3-bit address across the 8 keys at the bit clock, so every key is sampled 1/8 o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
PWR_FLAGs: tell ERC that +3V3 / GND are driven.
DISCRETE LOGIC SERIAL MACROPAD

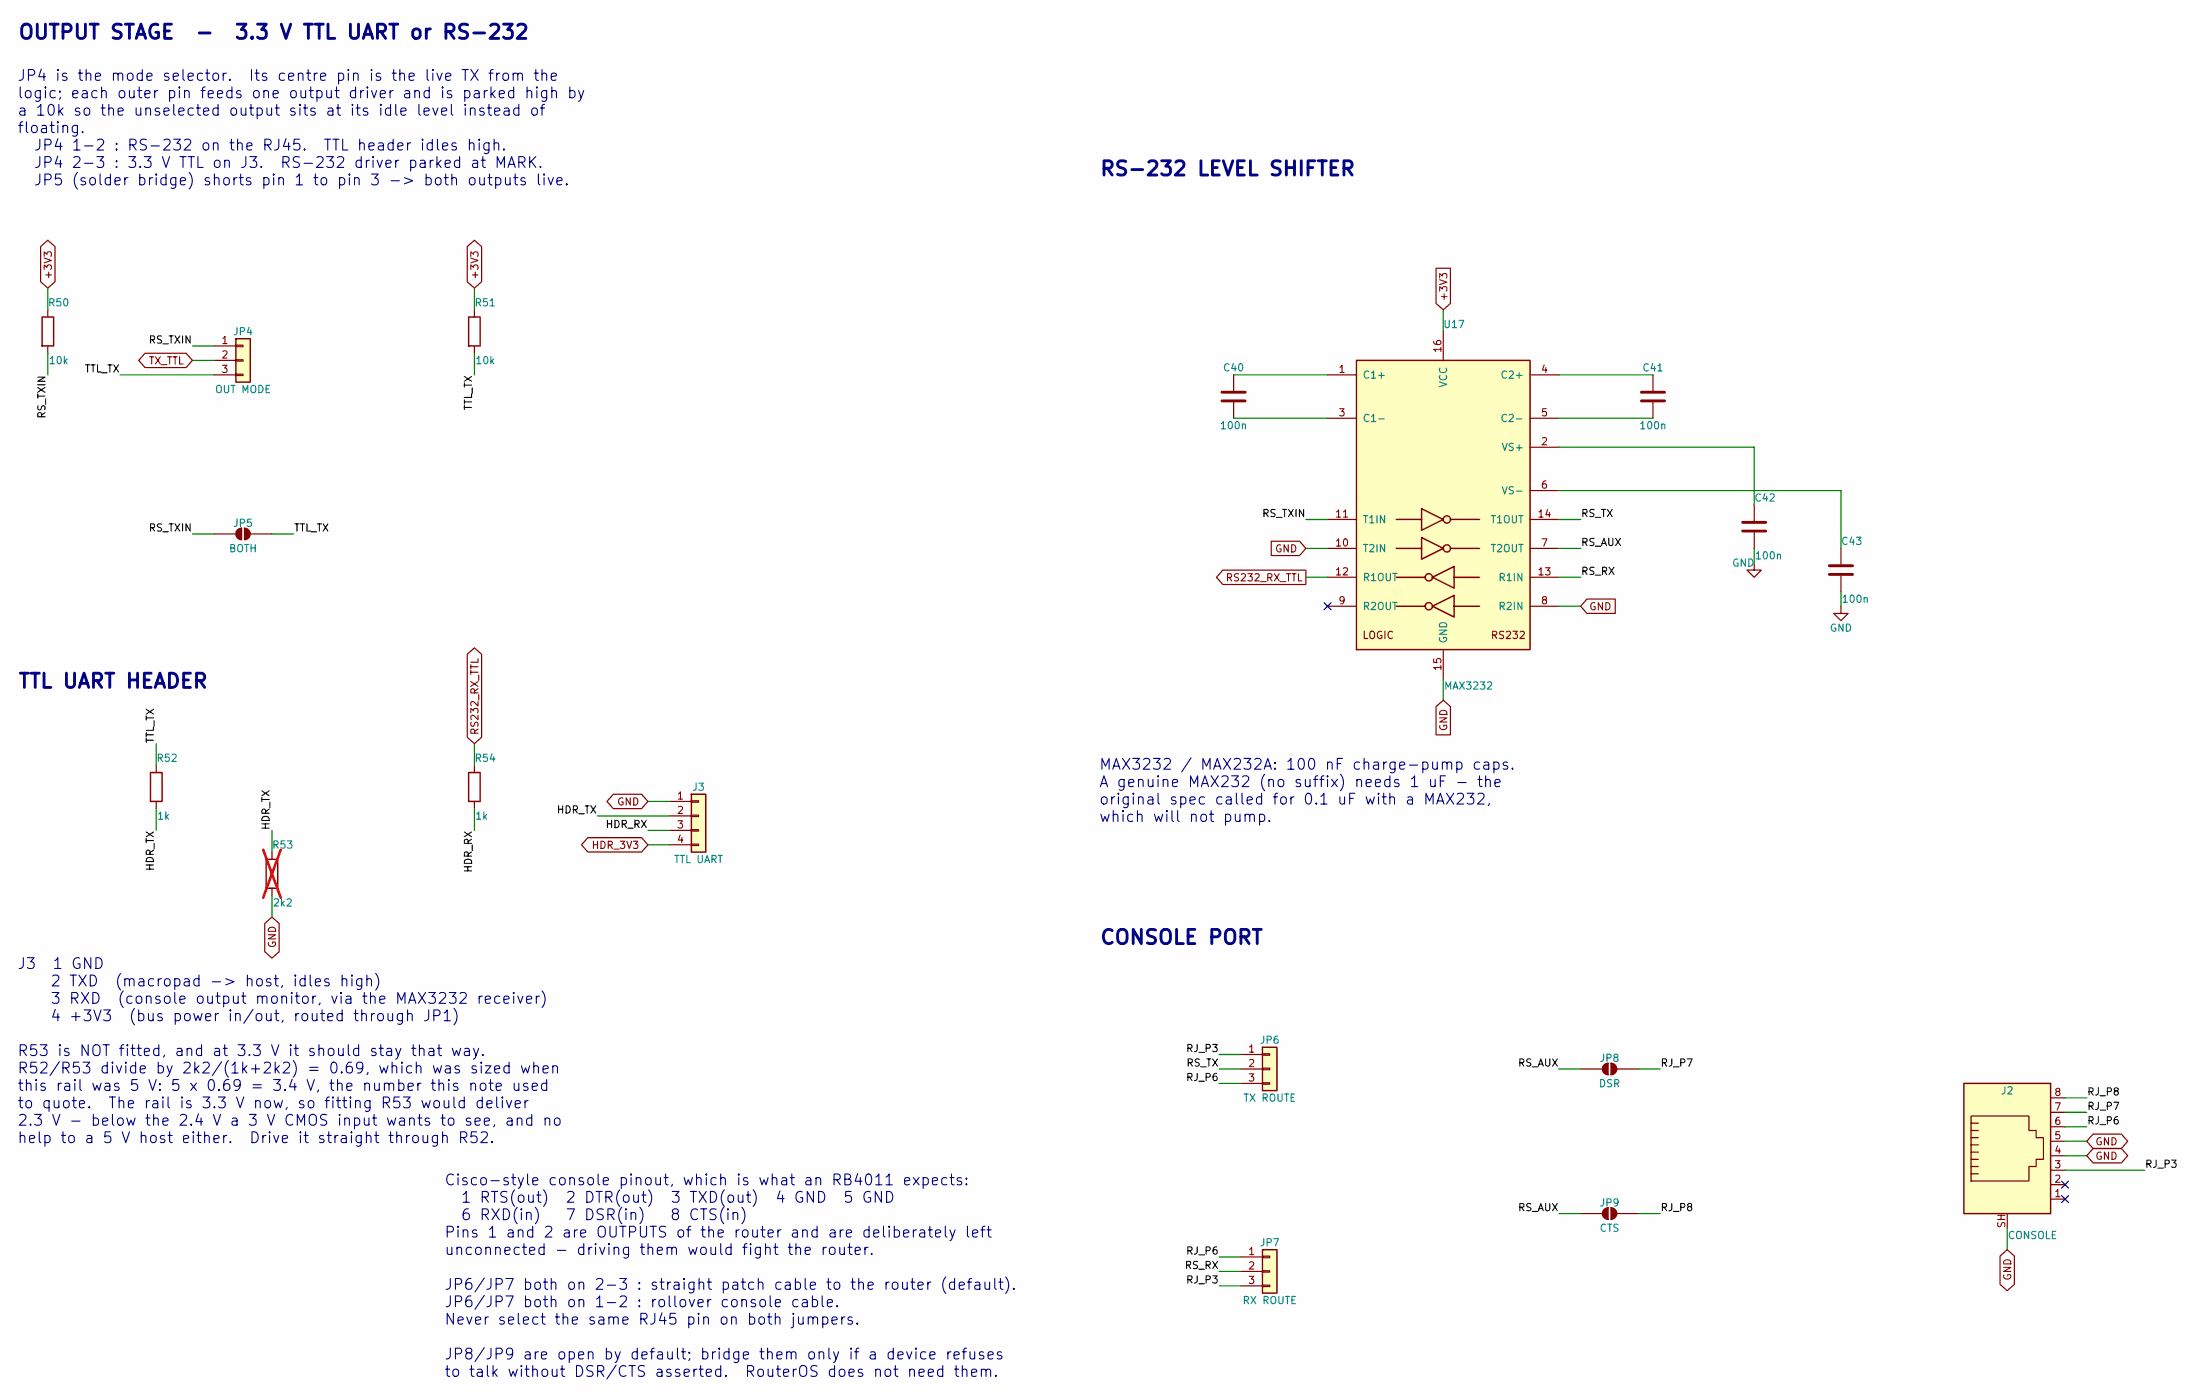
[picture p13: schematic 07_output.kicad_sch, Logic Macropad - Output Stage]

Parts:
C40, C41, C42, C43: 100n; C_0402_1005Metric; MPN GRM155R71H104KE14D
J2: CONSOLE; RJ45_8P8C_Shielded_HCTL_HC-RJ45-5JA-1-4; MPN HC-RJ45-5JA-1-4
J3: TTL UART; PinHeader_1x04_P2.54mm_Vertical; MPN 2.54-1*40P
JP4: OUT MODE; PinHeader_1x03_P2.54mm_Vertical; MPN 2.54-1*40P
JP5: BOTH; SolderJumper-2_P1.3mm_Open_RoundedPad1.0x1.5mm
JP6: TX ROUTE; PinHeader_1x03_P2.54mm_Vertical; MPN 2.54-1*40P
JP7: RX ROUTE; PinHeader_1x03_P2.54mm_Vertical; MPN 2.54-1*40P
JP8: DSR; SolderJumper-2_P1.3mm_Open_RoundedPad1.0x1.5mm
JP9: CTS; SolderJumper-2_P1.3mm_Open_RoundedPad1.0x1.5mm
R50, R51: 10k; R_0603_1608Metric
R52, R54: 1k; R_0603_1608Metric
R53: 2k2; R_0603_1608Metric; not fitted
U17: MAX3232; SOIC-16_3.9x9.9mm_P1.27mm; MPN MAX3232CSE+

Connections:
+3V3: R50.1, R51.1, U17.16 (VCC); also elsewhere on the board
/Output Stage/HDR_RX: J3.3, R54.2
/Output Stage/HDR_TX: J3.2, R52.2, R53.1
/Output Stage/RJ_P3: J2.3, JP6.1, JP7.3
/Output Stage/RJ_P6: J2.6, JP6.3, JP7.1
/Output Stage/RJ_P7: J2.7, JP8.2 (B)
/Output Stage/RJ_P8: J2.8, JP9.2 (B)
/Output Stage/RS_AUX: JP8.1 (A), JP9.1 (A), U17.7 (T2OUT)
/Output Stage/RS_RX: JP7.2, U17.13 (R1IN)
/Output Stage/RS_TX: JP6.2, U17.14 (T1OUT)
/Output Stage/RS_TXIN: JP4.1, JP5.1 (A), R50.2, U17.11 (T1IN)
/Output Stage/TTL_TX: JP4.3, JP5.2 (B), R51.2, R52.1
GND: C42.2, C43.2, J2.4, J2.5, J2.SH, J3.1, R53.2, U17.8 (R2IN), U17.10 (T2IN), U17.15 (GND); also elsewhere on the board
HDR_3V3: J3.4; also elsewhere on the board
unnamed: C40.1, U17.1 (C1+)
unnamed: C40.2, U17.3 (C1-)
unnamed: C41.1, U17.4 (C2+)
unnamed: C41.2, U17.5 (C2-)
unnamed: C42.1, U17.2 (VS+)
unnamed: C43.1, U17.6 (VS-)
RS232_RX_TTL: R54.1, U17.12 (R1OUT)
TX_TTL: JP4.2; also elsewhere on the board

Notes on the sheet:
OUTPUT STAGE - 3.3 V TTL UART or RS-232
Cisco-style console pinout, which is what an RB4011 expects: 1 RTS(out) 2 DTR(out) 3 TXD(out) 4 GND 5 GND 6 RXD(in) 7 DSR(in) 8 CTS(in) Pins 1 and 2 are OUTPUTS of the router and are deliberately left unconnected - driving them would fight the router. JP6/JP7 both on 2-3 : straight patch cable to t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
J3 1 GND 2 TXD (macropad -> host, idles high) 3 RXD (console output monitor, via the MAX3232 receiver) 4 +3V3 (bus power in/out, routed through JP1) R53 is NOT fitted, and at 3.3 V it should stay that way. R52/R53 divide by 2k2/(1k+2k2) = 0.69, which was sized when this rail was 5 V: 5 x 0.69 = 3.4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
JP4 is the mode selector. Its centre pin is the live TX from the logic; each outer pin feeds one output driver and is parked high by a 10k so the unselected output sits at its idle level instead of floating. JP4 1-2 : RS-232 on the RJ45. TTL header idles high. JP4 2-3 : 3.3 V TTL on J3. RS-232 driv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
RS-232 LEVEL SHIFTER
TTL UART HEADER
MAX3232 / MAX232A: 100 nF charge-pump caps. A genuine MAX232 (no suffix) needs 1 uF - the original spec called for 0.1 uF with a MAX232, which will not pump.
CONSOLE PORT

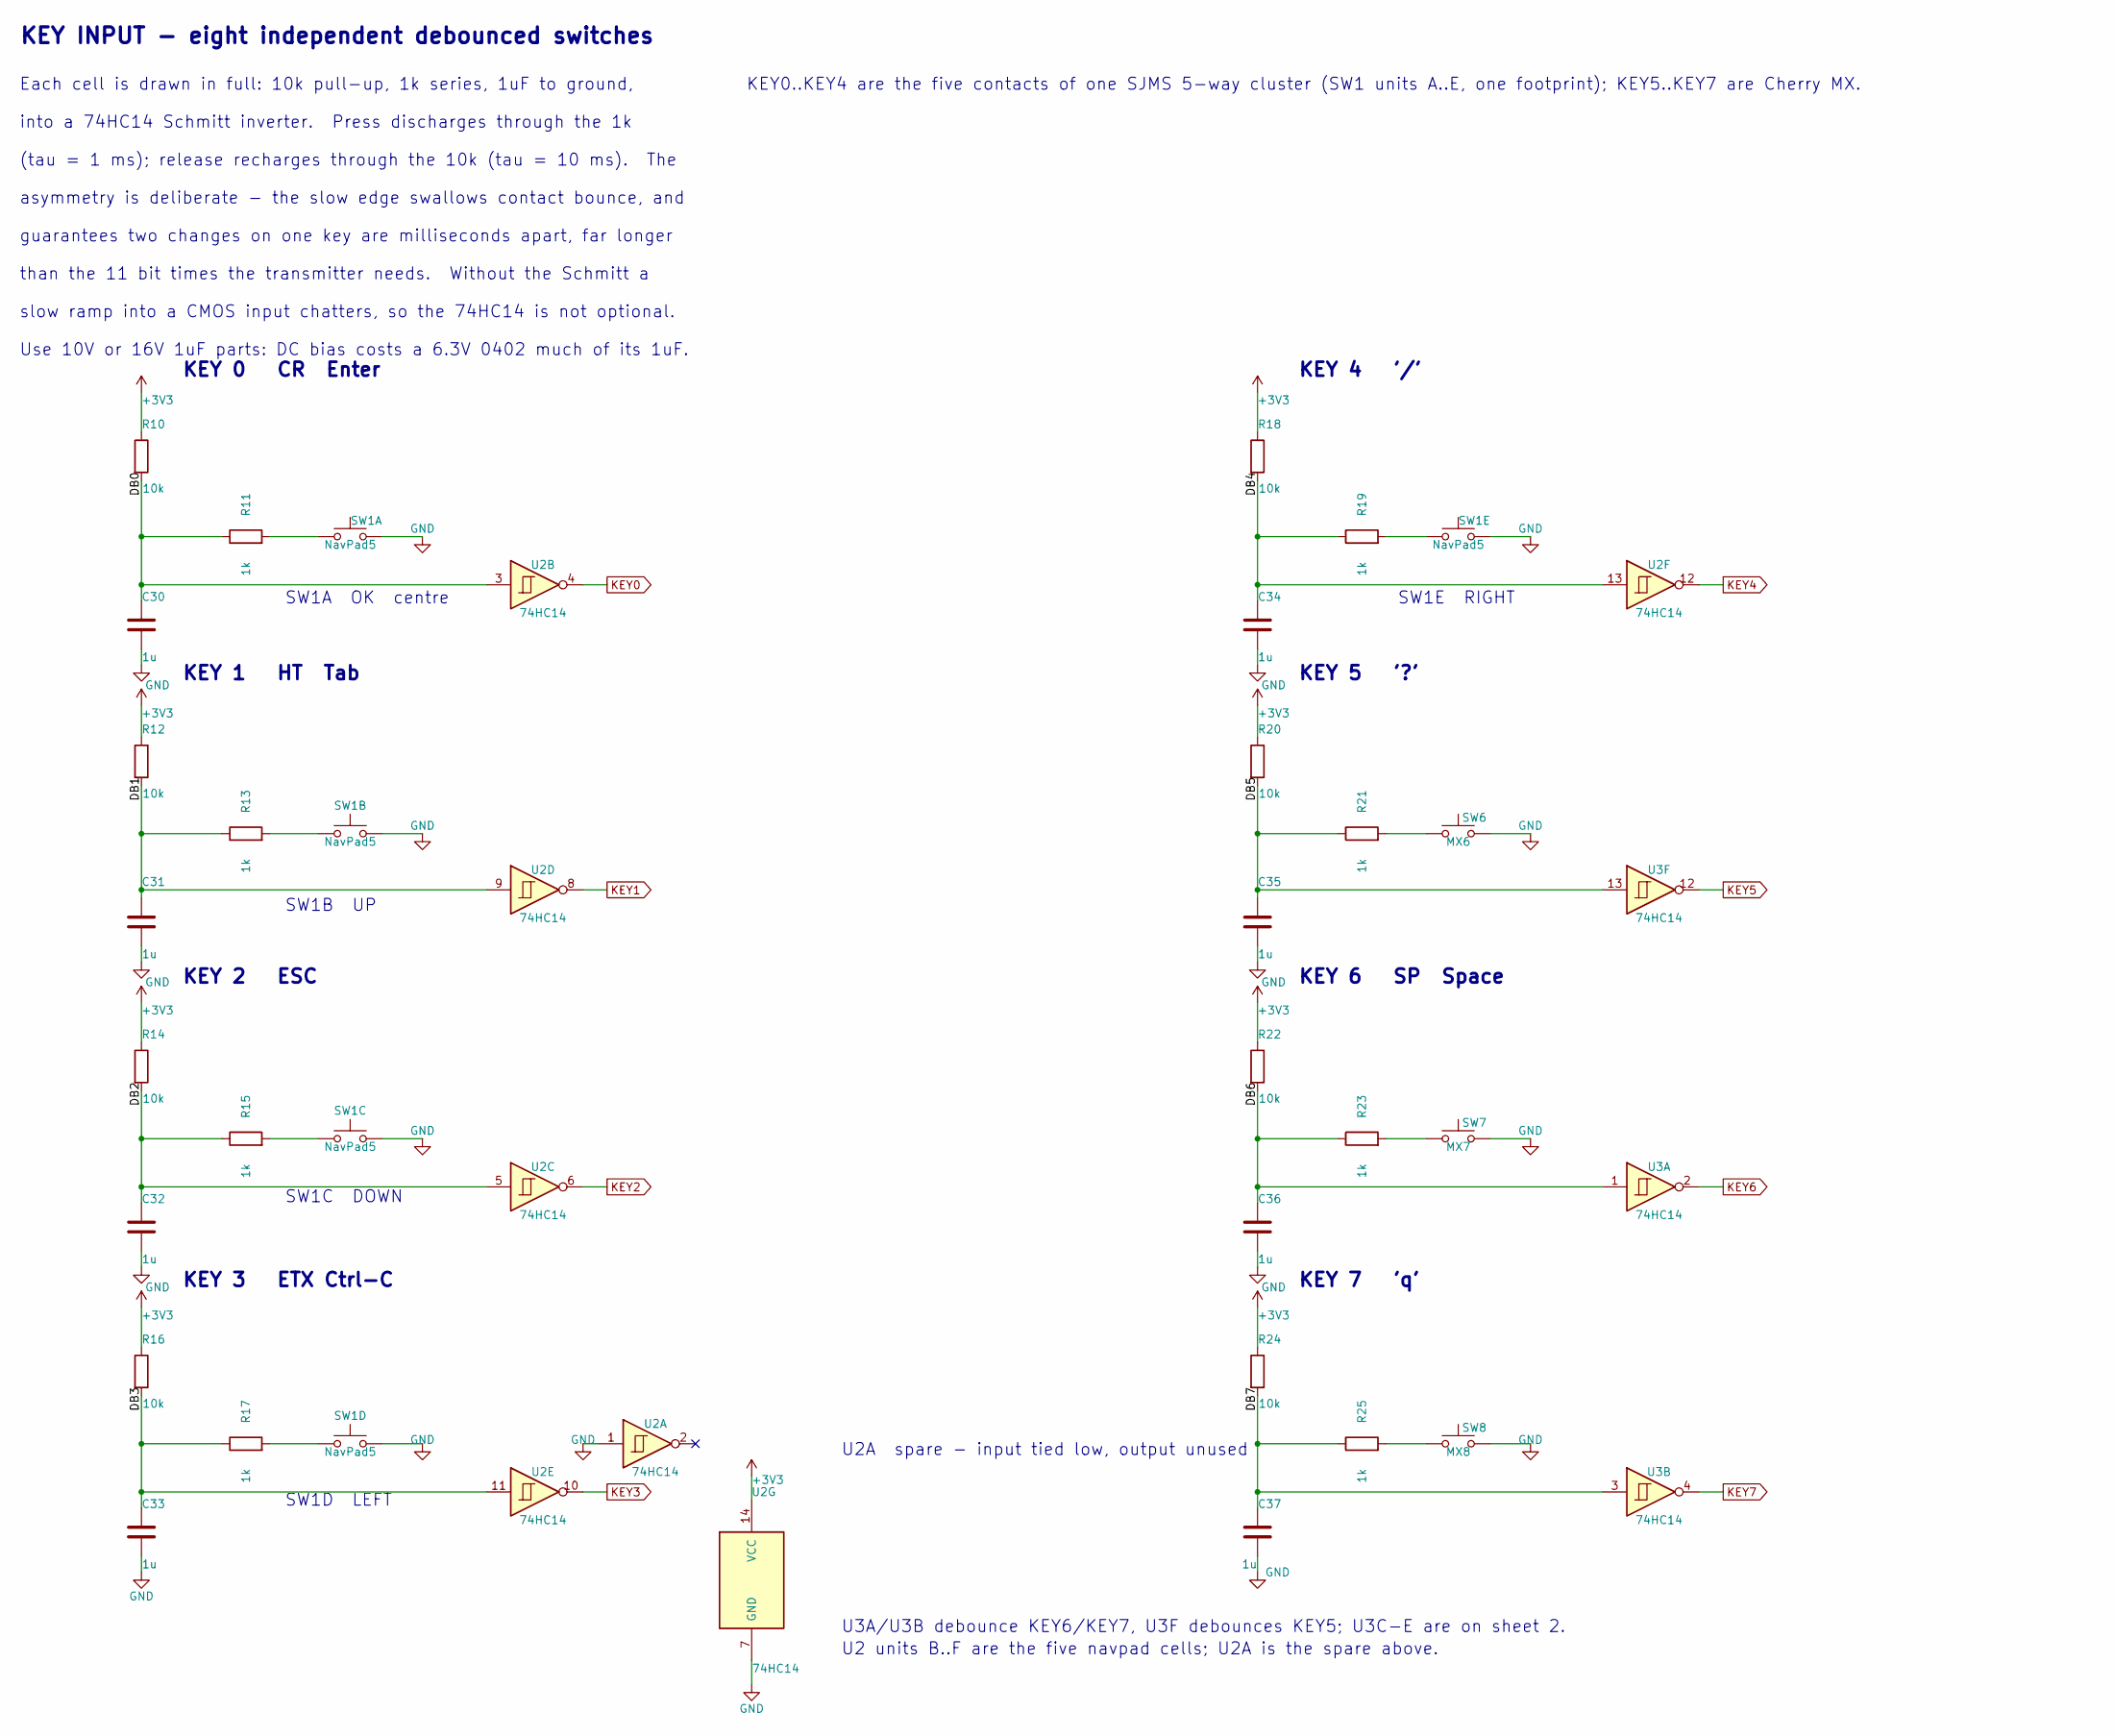
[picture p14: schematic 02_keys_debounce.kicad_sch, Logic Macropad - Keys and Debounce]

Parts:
C30, C31, C32, C33, C34, C35, C36, C37: 1u; C_0805_2012Metric; MPN GRM21BR71H105KA12L
R10, R12, R14, R16, R18, R20, R22, R24: 10k; R_0603_1608Metric
R11, R13, R15, R17, R19, R21, R23, R25: 1k; R_0603_1608Metric
SW1: NavPad5; SW_NavPad5_12x12_SJMS
SW6: MX6; SW_Cherry_MX_1.00u_PCB
SW7: MX7; SW_Cherry_MX_1.00u_PCB
SW8: MX8; SW_Cherry_MX_1.00u_PCB
U2, U3: 74HC14; SOIC-14_3.9x8.7mm_P1.27mm; MPN 74HC14D

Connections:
+3V3: R10.1, R12.1, R14.1, R16.1, R18.1, R20.1, R22.1, R24.1, U2.14 (VCC); also elsewhere on the board
/Keys and Debounce/DB0: C30.1, R10.2, R11.1, U2.3
/Keys and Debounce/DB1: C31.1, R12.2, R13.1, U2.9
/Keys and Debounce/DB2: C32.1, R14.2, R15.1, U2.5
/Keys and Debounce/DB3: C33.1, R16.2, R17.1, U2.11
/Keys and Debounce/DB4: C34.1, R18.2, R19.1, U2.13
/Keys and Debounce/DB5: C35.1, R20.2, R21.1, U3.13
/Keys and Debounce/DB6: C36.1, R22.2, R23.1, U3.1
/Keys and Debounce/DB7: C37.1, R24.2, R25.1, U3.3
GND: C30.2, C31.2, C32.2, C33.2, C34.2, C35.2, C36.2, C37.2, SW1.2, SW1.4 (2), SW1.6 (2), SW1.8 (2), SW1.10 (2), SW6.2, SW7.2, SW8.2, U2.1, U2.7 (GND); also elsewhere on the board
KEY0: U2.4; also elsewhere on the board
KEY1: U2.8; also elsewhere on the board
KEY2: U2.6; also elsewhere on the board
KEY3: U2.10; also elsewhere on the board
KEY4: U2.12; also elsewhere on the board
KEY5: U3.12; also elsewhere on the board
KEY6: U3.2; also elsewhere on the board
KEY7: U3.4; also elsewhere on the board
unnamed: R11.2, SW1.1
unnamed: R21.2, SW6.1
unnamed: R23.2, SW7.1
unnamed: R25.2, SW8.1
unnamed: R13.2, SW1.3 (1)
unnamed: R15.2, SW1.5 (1)
unnamed: R17.2, SW1.7 (1)
unnamed: R19.2, SW1.9 (1)

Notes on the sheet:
into a 74HC14 Schmitt inverter. Press discharges through the 1k
SW1E RIGHT
U3A/U3B debounce KEY6/KEY7, U3F debounces KEY5; U3C-E are on sheet 2.
KEY 1 HT Tab
asymmetry is deliberate - the slow edge swallows contact bounce, and
KEY 7 'q'
KEY0..KEY4 are the five contacts of one SJMS 5-way cluster (SW1 units A..E, one footprint); KEY5..KEY7 are Cherry MX.
SW1C DOWN
U2A spare - input tied low, output unused
U2 units B..F are the five navpad cells; U2A is the spare above.
KEY 4 '/'
Use 10V or 16V 1uF parts: DC bias costs a 6.3V 0402 much of its 1uF.
KEY 5 '?'
slow ramp into a CMOS input chatters, so the 74HC14 is not optional.
than the 11 bit times the transmitter needs. Without the Schmitt a
KEY 6 SP Space
(tau = 1 ms); release recharges through the 10k (tau = 10 ms). The
SW1B UP
SW1D LEFT
Each cell is drawn in full: 10k pull-up, 1k series, 1uF to ground,
KEY 0 CR Enter
KEY 2 ESC
KEY INPUT - eight independent debounced switches
SW1A OK centre
KEY 3 ETX Ctrl-C
guarantees two changes on one key are milliseconds apart, far longer

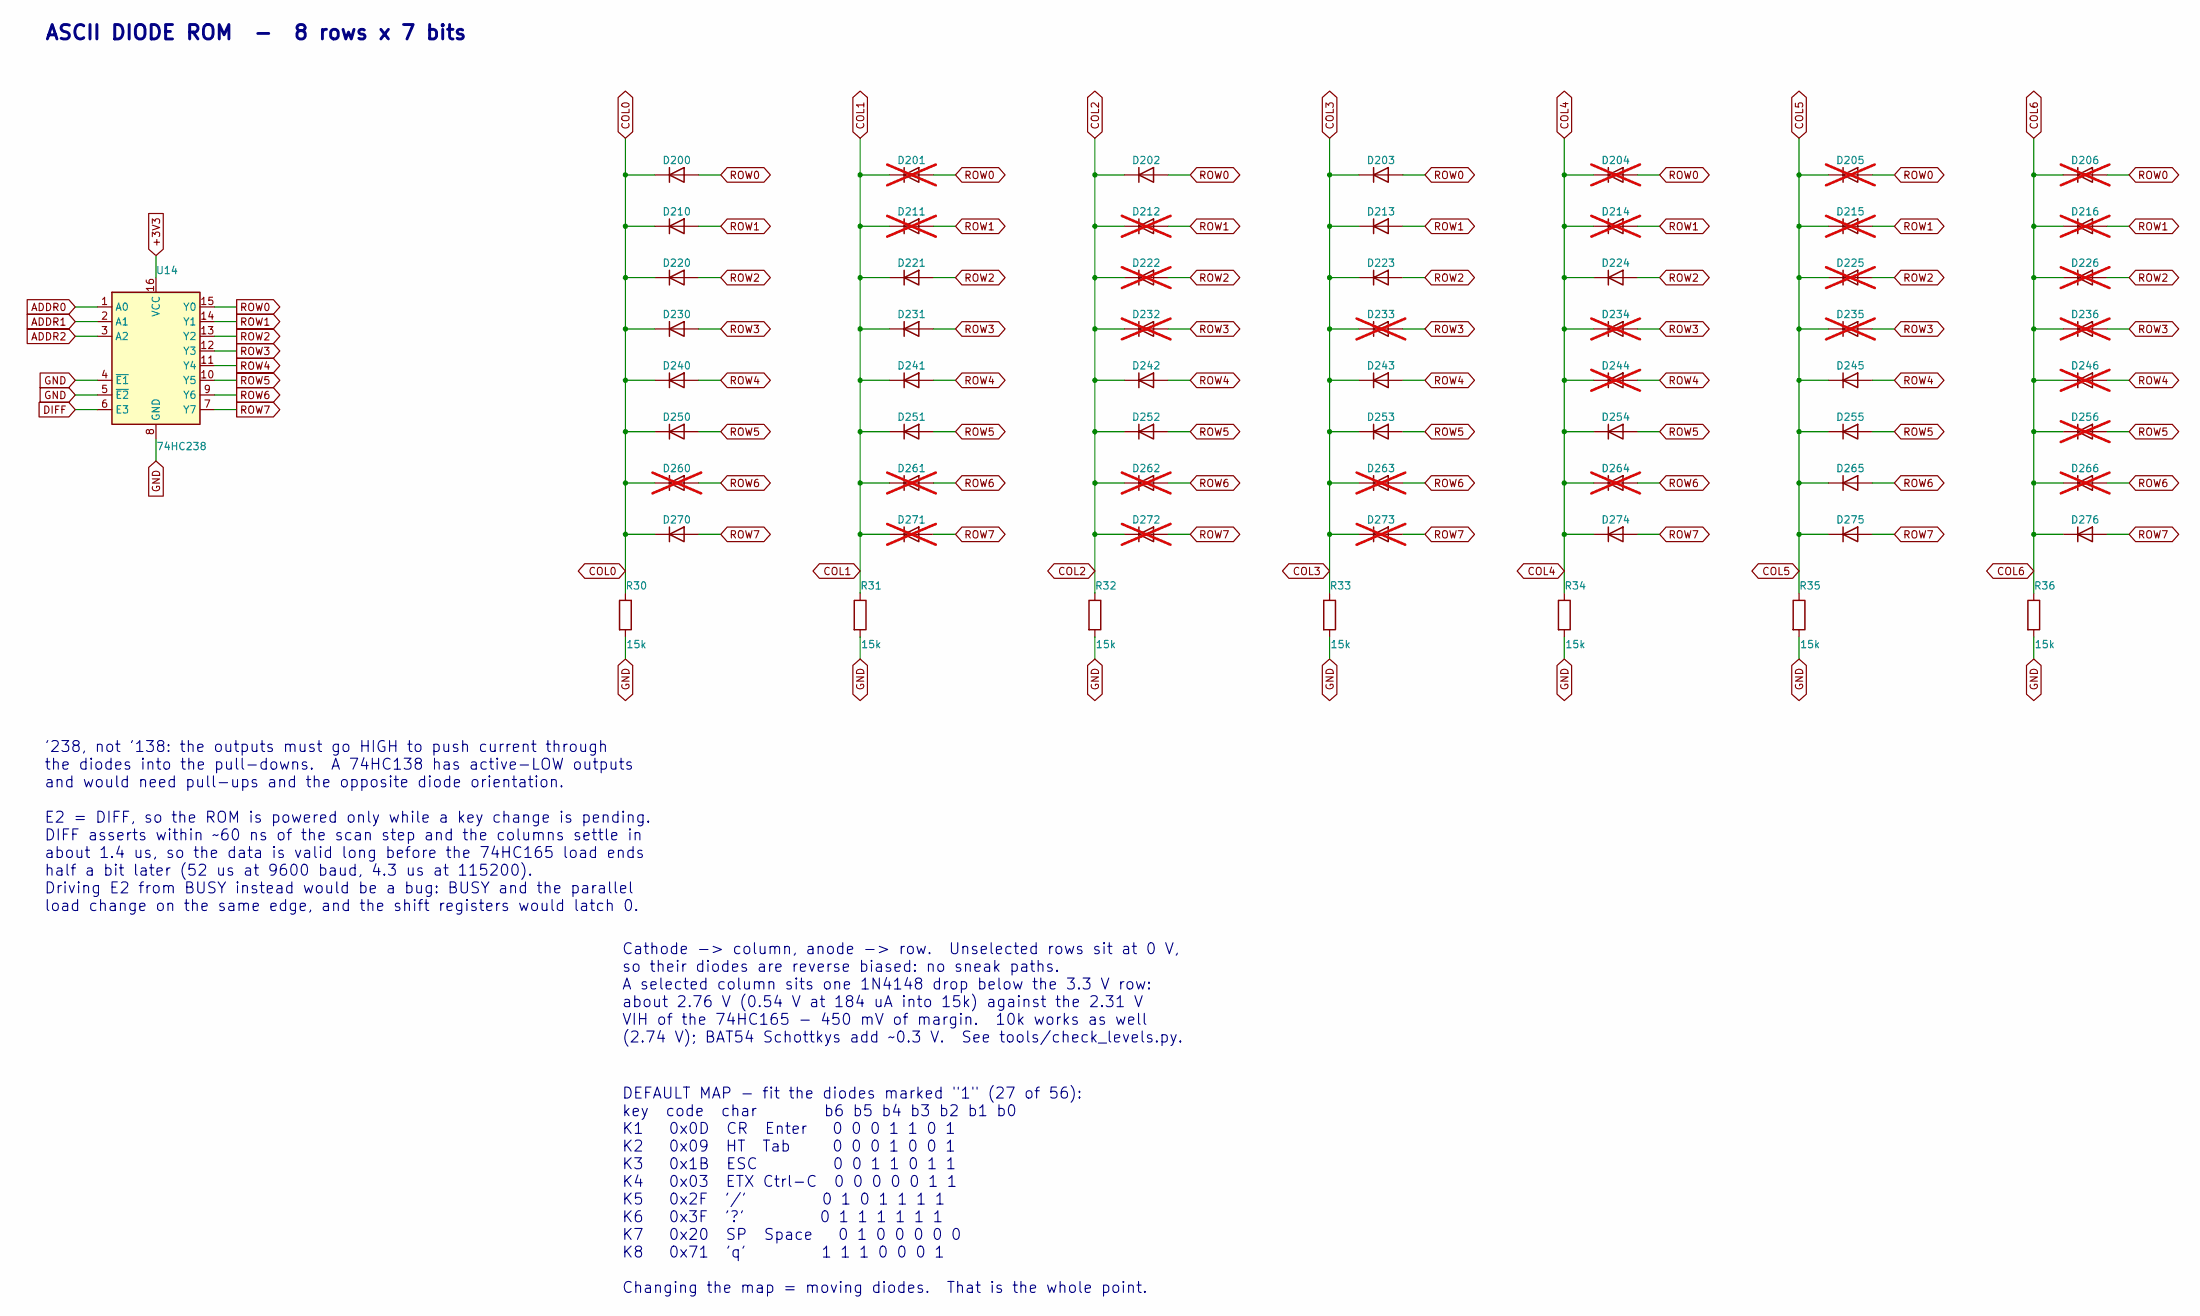
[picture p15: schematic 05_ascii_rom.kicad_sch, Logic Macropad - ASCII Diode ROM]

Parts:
D200, D202, D203, D210, D213, D220, D221, D223, D224, D230, D231, D240, D241, D242, D243, D245, D250, D251, D252, D253, D254, D255, D265, D270, D274, D275, D276: 1N4148; D_SOD-523; MPN 1N4148WT-7
D201, D204, D205, D206, D211, D212, D214, D215, D216, D222, D225, D226, D232, D233, D234, D235, D236, D244, D246, D256, D260, D261, D262, D263, D264, D266, D271, D272, D273: 1N4148; D_SOD-523; not fitted
R30, R31, R32, R33, R34, R35, R36: 15k; R_0603_1608Metric
U14: 74HC238; SOIC-16_3.9x9.9mm_P1.27mm; MPN 74HC238D

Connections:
+3V3: U14.16 (VCC); also elsewhere on the board
ADDR0: U14.1 (A0); also elsewhere on the board
ADDR1: U14.2 (A1); also elsewhere on the board
ADDR2: U14.3 (A2); also elsewhere on the board
COL0: D200.1 (K), D210.1 (K), D220.1 (K), D230.1 (K), D240.1 (K), D250.1 (K), D260.1 (K), D270.1 (K), R30.1; also elsewhere on the board
COL1: D201.1 (K), D211.1 (K), D221.1 (K), D231.1 (K), D241.1 (K), D251.1 (K), D261.1 (K), D271.1 (K), R31.1; also elsewhere on the board
COL2: D202.1 (K), D212.1 (K), D222.1 (K), D232.1 (K), D242.1 (K), D252.1 (K), D262.1 (K), D272.1 (K), R32.1; also elsewhere on the board
COL3: D203.1 (K), D213.1 (K), D223.1 (K), D233.1 (K), D243.1 (K), D253.1 (K), D263.1 (K), D273.1 (K), R33.1; also elsewhere on the board
COL4: D204.1 (K), D214.1 (K), D224.1 (K), D234.1 (K), D244.1 (K), D254.1 (K), D264.1 (K), D274.1 (K), R34.1; also elsewhere on the board
COL5: D205.1 (K), D215.1 (K), D225.1 (K), D235.1 (K), D245.1 (K), D255.1 (K), D265.1 (K), D275.1 (K), R35.1; also elsewhere on the board
COL6: D206.1 (K), D216.1 (K), D226.1 (K), D236.1 (K), D246.1 (K), D256.1 (K), D266.1 (K), D276.1 (K), R36.1; also elsewhere on the board
DIFF: U14.6 (E3); also elsewhere on the board
GND: R30.2, R31.2, R32.2, R33.2, R34.2, R35.2, R36.2, U14.4 (~E1), U14.5 (~E2), U14.8 (GND); also elsewhere on the board
ROW0: D200.2 (A), D201.2 (A), D202.2 (A), D203.2 (A), D204.2 (A), D205.2 (A), D206.2 (A), U14.15 (Y0)
ROW1: D210.2 (A), D211.2 (A), D212.2 (A), D213.2 (A), D214.2 (A), D215.2 (A), D216.2 (A), U14.14 (Y1)
ROW2: D220.2 (A), D221.2 (A), D222.2 (A), D223.2 (A), D224.2 (A), D225.2 (A), D226.2 (A), U14.13 (Y2)
ROW3: D230.2 (A), D231.2 (A), D232.2 (A), D233.2 (A), D234.2 (A), D235.2 (A), D236.2 (A), U14.12 (Y3)
ROW4: D240.2 (A), D241.2 (A), D242.2 (A), D243.2 (A), D244.2 (A), D245.2 (A), D246.2 (A), U14.11 (Y4)
ROW5: D250.2 (A), D251.2 (A), D252.2 (A), D253.2 (A), D254.2 (A), D255.2 (A), D256.2 (A), U14.10 (Y5)
ROW6: D260.2 (A), D261.2 (A), D262.2 (A), D263.2 (A), D264.2 (A), D265.2 (A), D266.2 (A), U14.9 (Y6)
ROW7: D270.2 (A), D271.2 (A), D272.2 (A), D273.2 (A), D274.2 (A), D275.2 (A), D276.2 (A), U14.7 (Y7)

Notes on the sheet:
DEFAULT MAP - fit the diodes marked "1" (27 of 56): key code char b6 b5 b4 b3 b2 b1 b0 K1 0x0D CR Enter 0 0 0 1 1 0 1 K2 0x09 HT Tab 0 0 0 1 0 0 1 K3 0x1B ESC 0 0 1 1 0 1 1 K4 0x03 ETX Ctrl-C 0 0 0 0 0 1 1 K5 0x2F '/' 0 1 0 1 1 1 1 K6 0x3F '?' 0 1 1 1 1 1 1 K7 0x20 SP Space 0 1 0 0 0 0 0 K8 0x71 'q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
'238, not '138: the outputs must go HIGH to push current through the diodes into the pull-downs. A 74HC138 has active-LOW outputs and would need pull-ups and the opposite diode orientation. E2 = DIFF, so the ROM is powered only while a key change is pending. DIFF asserts within ~60 ns of the scan s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
Cathode -> column, anode -> row. Unselected rows sit at 0 V, so their diodes are reverse biased: no sneak paths. A selected column sits one 1N4148 drop below the 3.3 V row: about 2.76 V (0.54 V at 184 uA into 15k) against the 2.31 V VIH of the 74HC165 - 450 mV of margin. 10k works as well (2.74 V);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
ASCII DIODE ROM - 8 rows x 7 bits

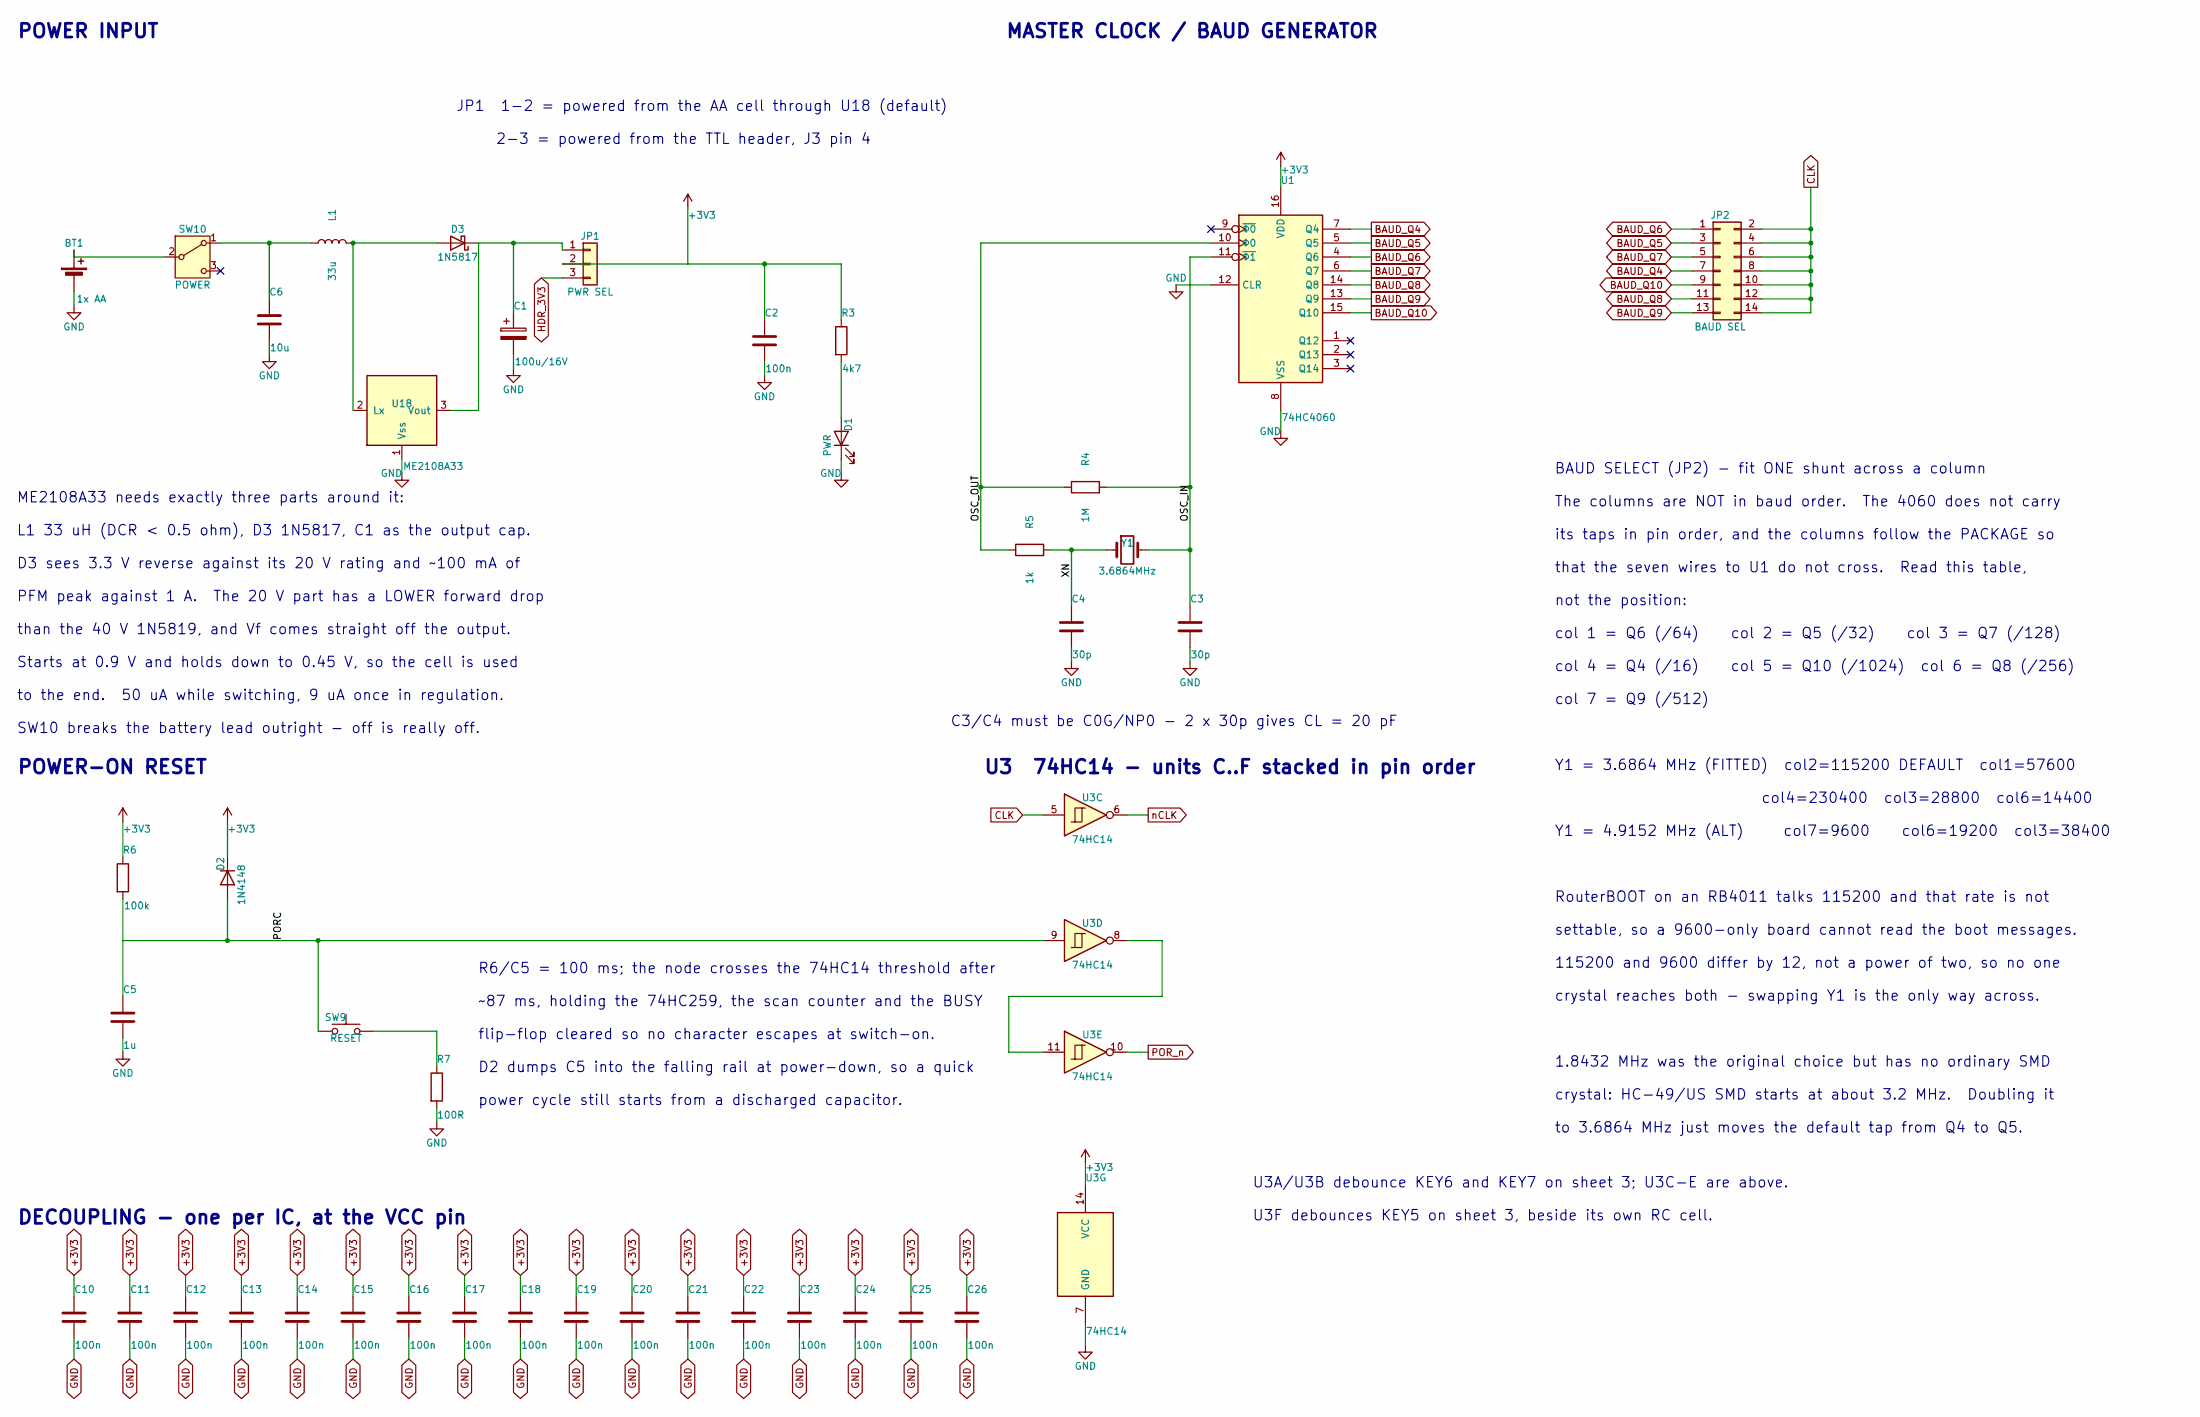
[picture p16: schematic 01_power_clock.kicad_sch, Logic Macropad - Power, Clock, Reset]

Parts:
BT1: 1x AA; BatteryHolder_MYOUNG_BH-AA-A1AJ020_1xAA; MPN BH-AA-A1AJ020
C1: 100u/16V; CP_Radial_D5.0mm_P2.00mm; MPN UVR1C101MED
C2, C10, C11, C12, C13, C14, C15, C16, C17, C18, C19, C20, C21, C22, C23, C24, C25, C26: 100n; C_0402_1005Metric; MPN GRM155R71H104KE14D
C3, C4: 30p; C_0402_1005Metric; MPN CC0402JRNPO9BN300
C5: 1u; C_0805_2012Metric; MPN GRM21BR71H105KA12L
C6: 10u; C_0805_2012Metric
D1: PWR; LED_0805_2012Metric_Pad1.15x1.40mm_HandSolder
D2: 1N4148; D_SOD-523; MPN 1N4148WT-7
D3: 1N5817; D_DO-41_SOD81_P10.16mm_Horizontal
JP1: PWR SEL; PinHeader_1x03_P2.54mm_Vertical; MPN 2.54-1*40P
JP2: BAUD SEL; PinHeader_2x07_P2.54mm_Vertical; MPN 2.54-2*7P
L1: 33u; L_Cenker_CKCS5040
R3: 4k7; R_0603_1608Metric
R4: 1M; R_0603_1608Metric
R5: 1k; R_0603_1608Metric
R6: 100k; R_0603_1608Metric
R7: 100R; R_0603_1608Metric
SW9: RESET; SW_PUSH_6mm; MPN K2-1102DP-F4SW-04
SW10: POWER; SW_Toggle_SPDT_ST-0-102; MPN ST-0-102-A01-T000-LF
U1: 74HC4060; SOIC-16_3.9x9.9mm_P1.27mm; MPN 74HC4060D
U3: 74HC14; SOIC-14_3.9x8.7mm_P1.27mm; MPN 74HC14D
U18: ME2108A33; SOT-23; MPN ME2108A33M3G
Y1: 3.6864MHz; Crystal_SMD_HC49-SD_HandSoldering; MPN ABLS-3.6864MHZ-B4-T

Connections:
+3V3: C2.1, C10.1, C11.1, C12.1, C13.1, C14.1, C15.1, C16.1, C17.1, C18.1, C19.1, C20.1, C21.1, C22.1, C23.1, C24.1, C25.1, C26.1, D2.1 (K), JP1.2, R3.1, R6.1, U1.16 (VDD), U3.14 (VCC); also elsewhere on the board
/Power, Clock, Reset/OSC_IN: C3.1, R4.2, U1.11 (~Φ1), Y1.2
/Power, Clock, Reset/OSC_OUT: R4.1, R5.1, U1.10 (Φ0)
/Power, Clock, Reset/PORC: C5.1, D2.2 (A), R6.2, SW9.1, U3.9
/Power, Clock, Reset/XN: C4.1, R5.2, Y1.1
BAUD_Q4: JP2.7, U1.7 (Q4)
BAUD_Q5: JP2.3, U1.5 (Q5)
BAUD_Q6: JP2.1, U1.4 (Q6)
BAUD_Q7: JP2.5, U1.6 (Q7)
BAUD_Q8: JP2.11, U1.14 (Q8)
BAUD_Q9: JP2.13, U1.13 (Q9)
BAUD_Q10: JP2.9, U1.15 (Q10)
CLK: JP2.2, JP2.4, JP2.6, JP2.8, JP2.10, JP2.12, JP2.14, U3.5; also elsewhere on the board
GND: BT1.2 (-), C1.2, C2.2, C3.2, C4.2, C5.2, C6.2, C10.2, C11.2, C12.2, C13.2, C14.2, C15.2, C16.2, C17.2, C18.2, C19.2, C20.2, C21.2, C22.2, C23.2, C24.2, C25.2, C26.2, D1.1 (K), R7.2, U1.8 (VSS), U1.12 (CLR), U3.7 (GND), U18.1 (Vss); also elsewhere on the board
HDR_3V3: JP1.3; also elsewhere on the board
unnamed: BT1.1 (+), SW10.2 (B)
unnamed: D1.2 (A), R3.2
unnamed: D3.2 (A), L1.2, U18.2 (Lx)
unnamed: C1.1, D3.1 (K), JP1.1, U18.3 (Vout)
unnamed: R7.1, SW9.2
unnamed: C6.1, L1.1, SW10.1 (A)
unnamed: U3.8, U3.11
POR_n: U3.10; also elsewhere on the board
nCLK: U3.6; also elsewhere on the board

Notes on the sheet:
flip-flop cleared so no character escapes at switch-on.
1.8432 MHz was the original choice but has no ordinary SMD
than the 40 V 1N5819, and Vf comes straight off the output.
col4=230400 col3=28800 col6=14400
settable, so a 9600-only board cannot read the boot messages.
Y1 = 3.6864 MHz (FITTED) col2=115200 DEFAULT col1=57600
crystal reaches both - swapping Y1 is the only way across.
POWER INPUT
The columns are NOT in baud order. The 4060 does not carry
col 4 = Q4 (/16) col 5 = Q10 (/1024) col 6 = Q8 (/256)
Starts at 0.9 V and holds down to 0.45 V, so the cell is used
its taps in pin order, and the columns follow the PACKAGE so
D3 sees 3.3 V reverse against its 20 V rating and ~100 mA of
R6/C5 = 100 ms; the node crosses the 74HC14 threshold after
not the position:
U3A/U3B debounce KEY6 and KEY7 on sheet 3; U3C-E are above.
col 7 = Q9 (/512)
2-3 = powered from the TTL header, J3 pin 4
BAUD SELECT (JP2) - fit ONE shunt across a column
Y1 = 4.9152 MHz (ALT) col7=9600 col6=19200 col3=38400
115200 and 9600 differ by 12, not a power of two, so no one
U3F debounces KEY5 on sheet 3, beside its own RC cell.
POWER-ON RESET
power cycle still starts from a discharged capacitor.
to the end. 50 uA while switching, 9 uA once in regulation.
PFM peak against 1 A. The 20 V part has a LOWER forward drop
U3 74HC14 - units C..F stacked in pin order
ME2108A33 needs exactly three parts around it:
C3/C4 must be C0G/NP0 - 2 x 30p gives CL = 20 pF
D2 dumps C5 into the falling rail at power-down, so a quick
MASTER CLOCK / BAUD GENERATOR
DECOUPLING - one per IC, at the VCC pin
to 3.6864 MHz just moves the default tap from Q4 to Q5.
SW10 breaks the battery lead outright - off is really off.
RouterBOOT on an RB4011 talks 115200 and that rate is not
JP1 1-2 = powered from the AA cell through U18 (default)
L1 33 uH (DCR < 0.5 ohm), D3 1N5817, C1 as the output cap.
that the seven wires to U1 do not cross. Read this table,
col 1 = Q6 (/64) col 2 = Q5 (/32) col 3 = Q7 (/128)
crystal: HC-49/US SMD starts at about 3.2 MHz. Doubling it

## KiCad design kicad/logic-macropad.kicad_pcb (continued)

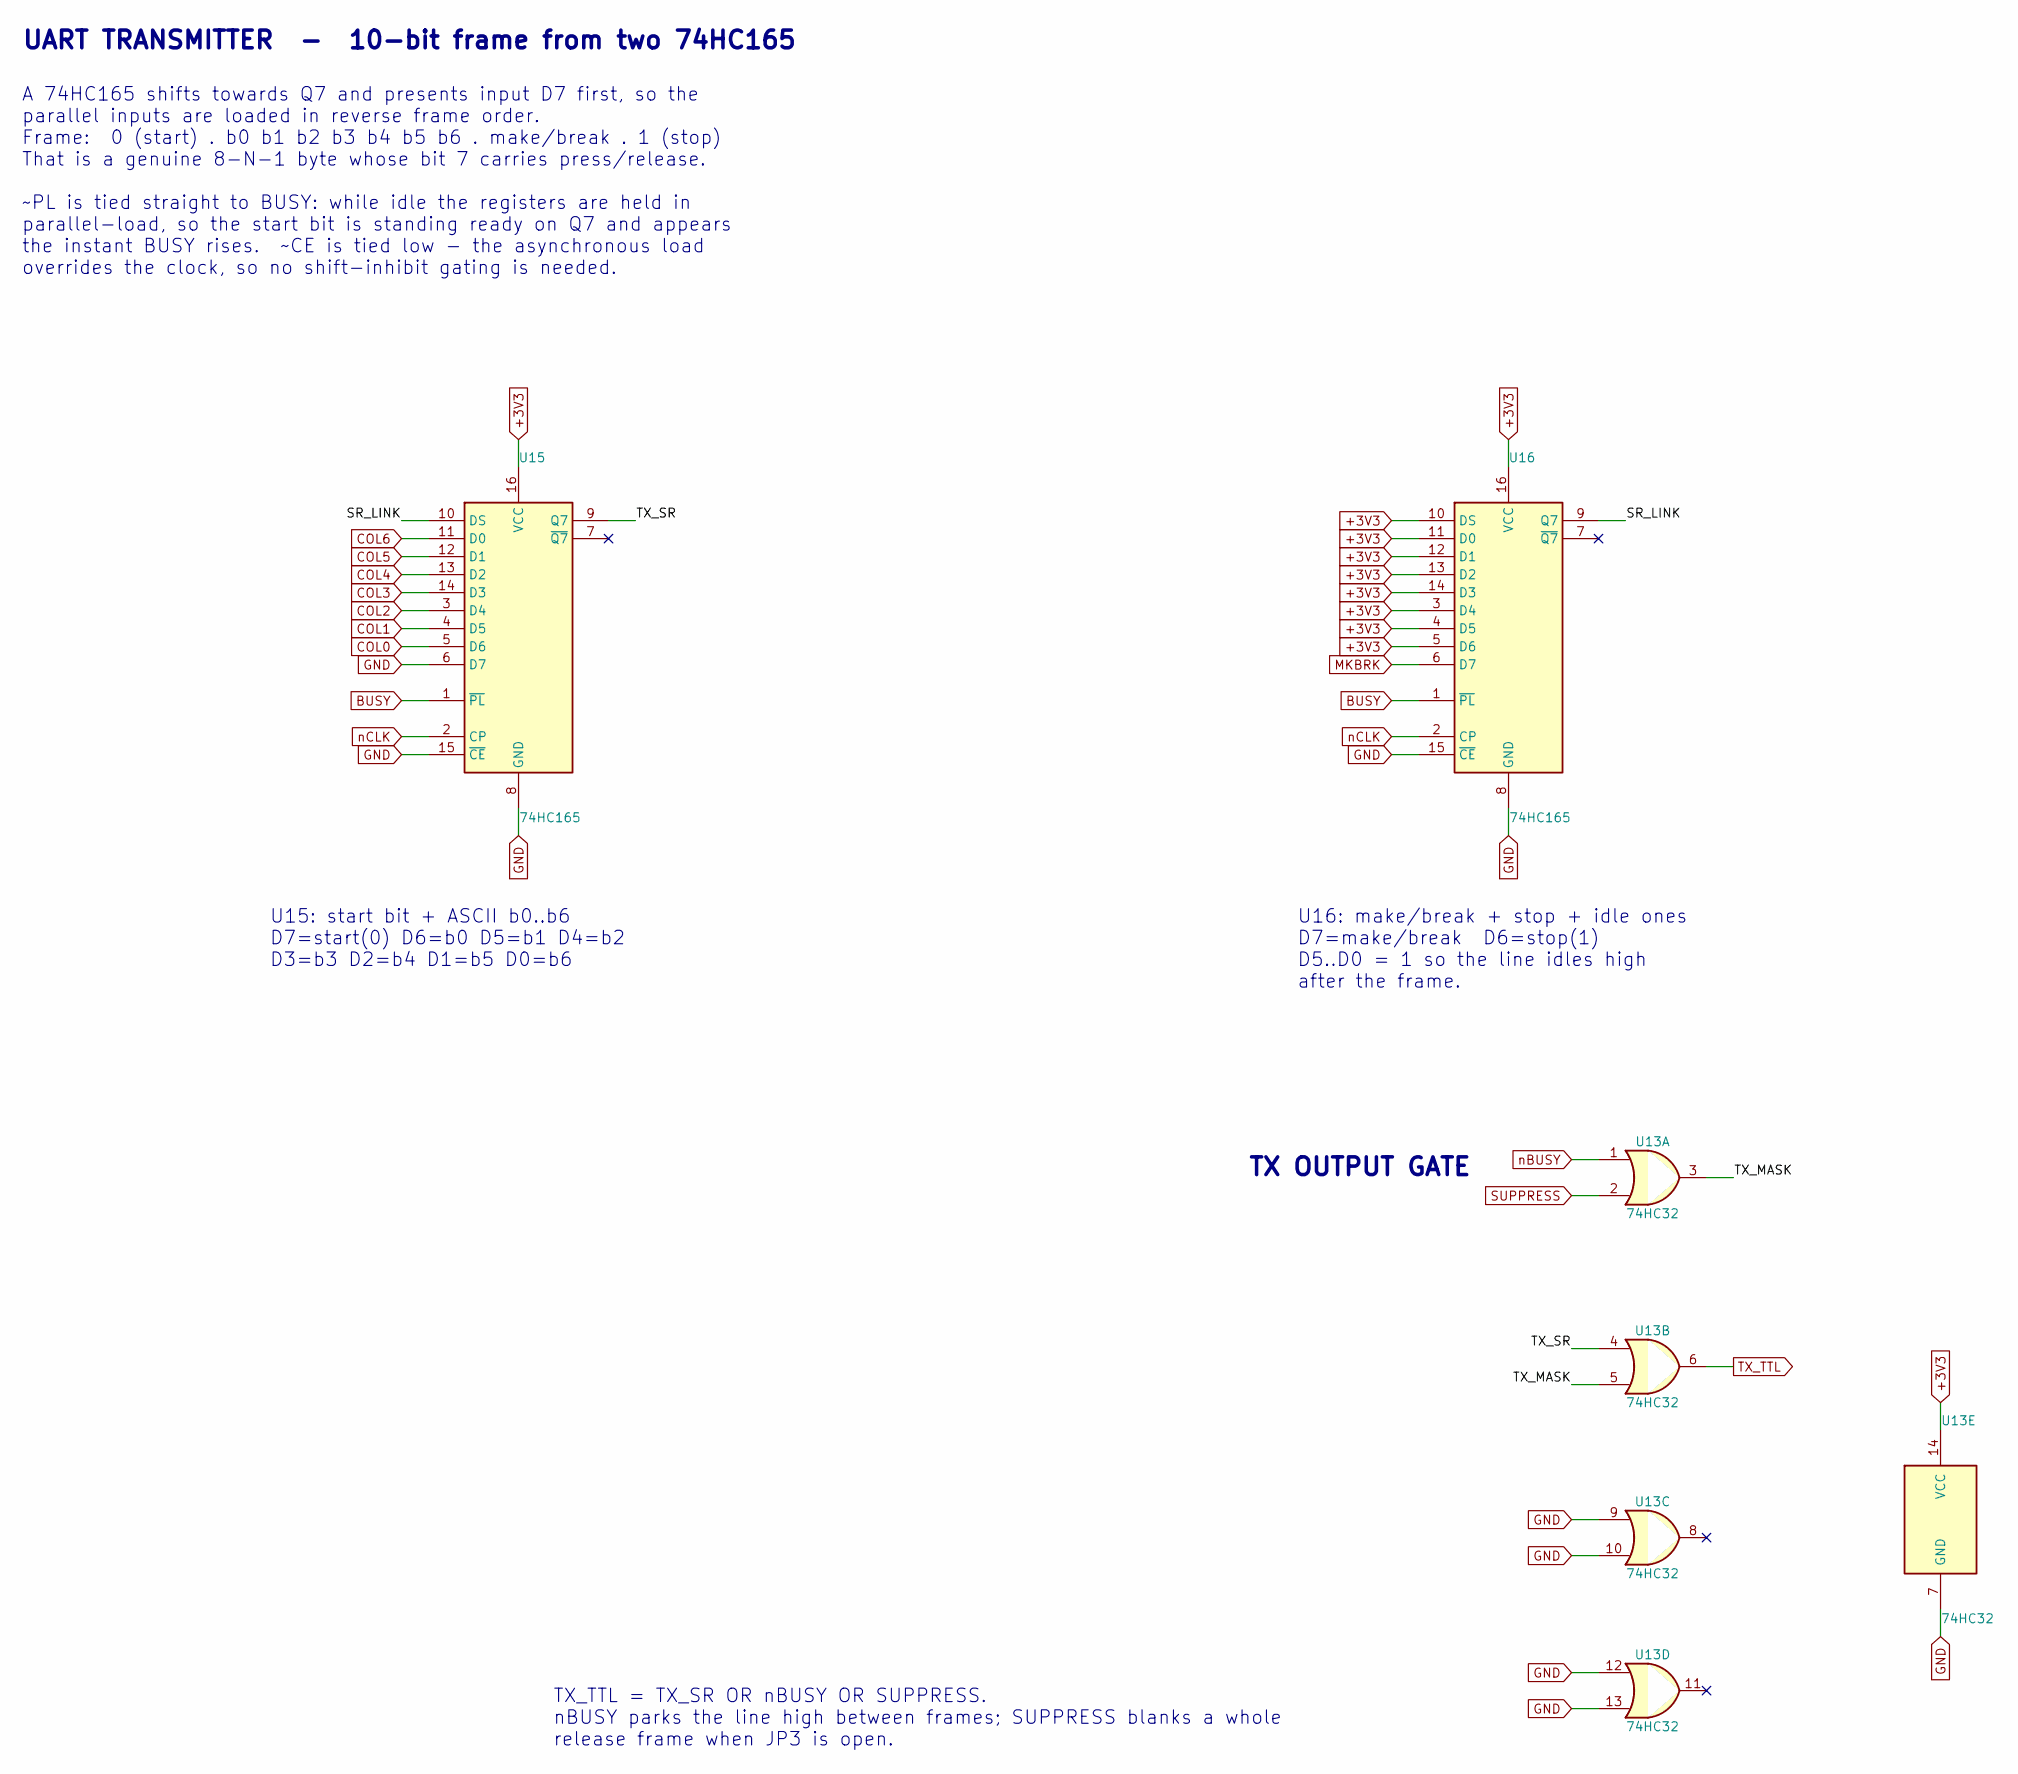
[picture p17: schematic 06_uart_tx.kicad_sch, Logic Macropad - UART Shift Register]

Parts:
U13: 74HC32; SOIC-14_3.9x8.7mm_P1.27mm; MPN 74HC32D
U15, U16: 74HC165; SOIC-16_3.9x9.9mm_P1.27mm; MPN 74HC165D

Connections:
+3V3: U13.14 (VCC), U15.16 (VCC), U16.3 (D4), U16.4 (D5), U16.5 (D6), U16.10 (DS), U16.11 (D0), U16.12 (D1), U16.13 (D2), U16.14 (D3), U16.16 (VCC); also elsewhere on the board
/UART Shift Register/SR_LINK: U15.10 (DS), U16.9 (Q7)
/UART Shift Register/TX_MASK: U13.3, U13.5
/UART Shift Register/TX_SR: U13.4, U15.9 (Q7)
BUSY: U15.1 (~PL), U16.1 (~PL); also elsewhere on the board
COL0: U15.5 (D6); also elsewhere on the board
COL1: U15.4 (D5); also elsewhere on the board
COL2: U15.3 (D4); also elsewhere on the board
COL3: U15.14 (D3); also elsewhere on the board
COL4: U15.13 (D2); also elsewhere on the board
COL5: U15.12 (D1); also elsewhere on the board
COL6: U15.11 (D0); also elsewhere on the board
GND: U13.7 (GND), U13.9, U13.10, U13.12, U13.13, U15.6 (D7), U15.8 (GND), U15.15 (~CE), U16.8 (GND), U16.15 (~CE); also elsewhere on the board
MKBRK: U16.6 (D7); also elsewhere on the board
SUPPRESS: U13.2; also elsewhere on the board
TX_TTL: U13.6; also elsewhere on the board
nBUSY: U13.1; also elsewhere on the board
nCLK: U15.2 (CP), U16.2 (CP); also elsewhere on the board

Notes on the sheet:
A 74HC165 shifts towards Q7 and presents input D7 first, so the parallel inputs are loaded in reverse frame order. Frame: 0 (start) . b0 b1 b2 b3 b4 b5 b6 . make/break . 1 (stop) That is a genuine 8-N-1 byte whose bit 7 carries press/release. ~PL is tied straight to BUSY: while idle the registers a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
UART TRANSMITTER - 10-bit frame from two 74HC165
TX_TTL = TX_SR OR nBUSY OR SUPPRESS. nBUSY parks the line high between frames; SUPPRESS blanks a whole release frame when JP3 is open.
U15: start bit + ASCII b0..b6 D7=start(0) D6=b0 D5=b1 D4=b2 D3=b3 D2=b4 D1=b5 D0=b6
U16: make/break + stop + idle ones D7=make/break D6=stop(1) D5..D0 = 1 so the line idles high after the frame.
TX OUTPUT GATE

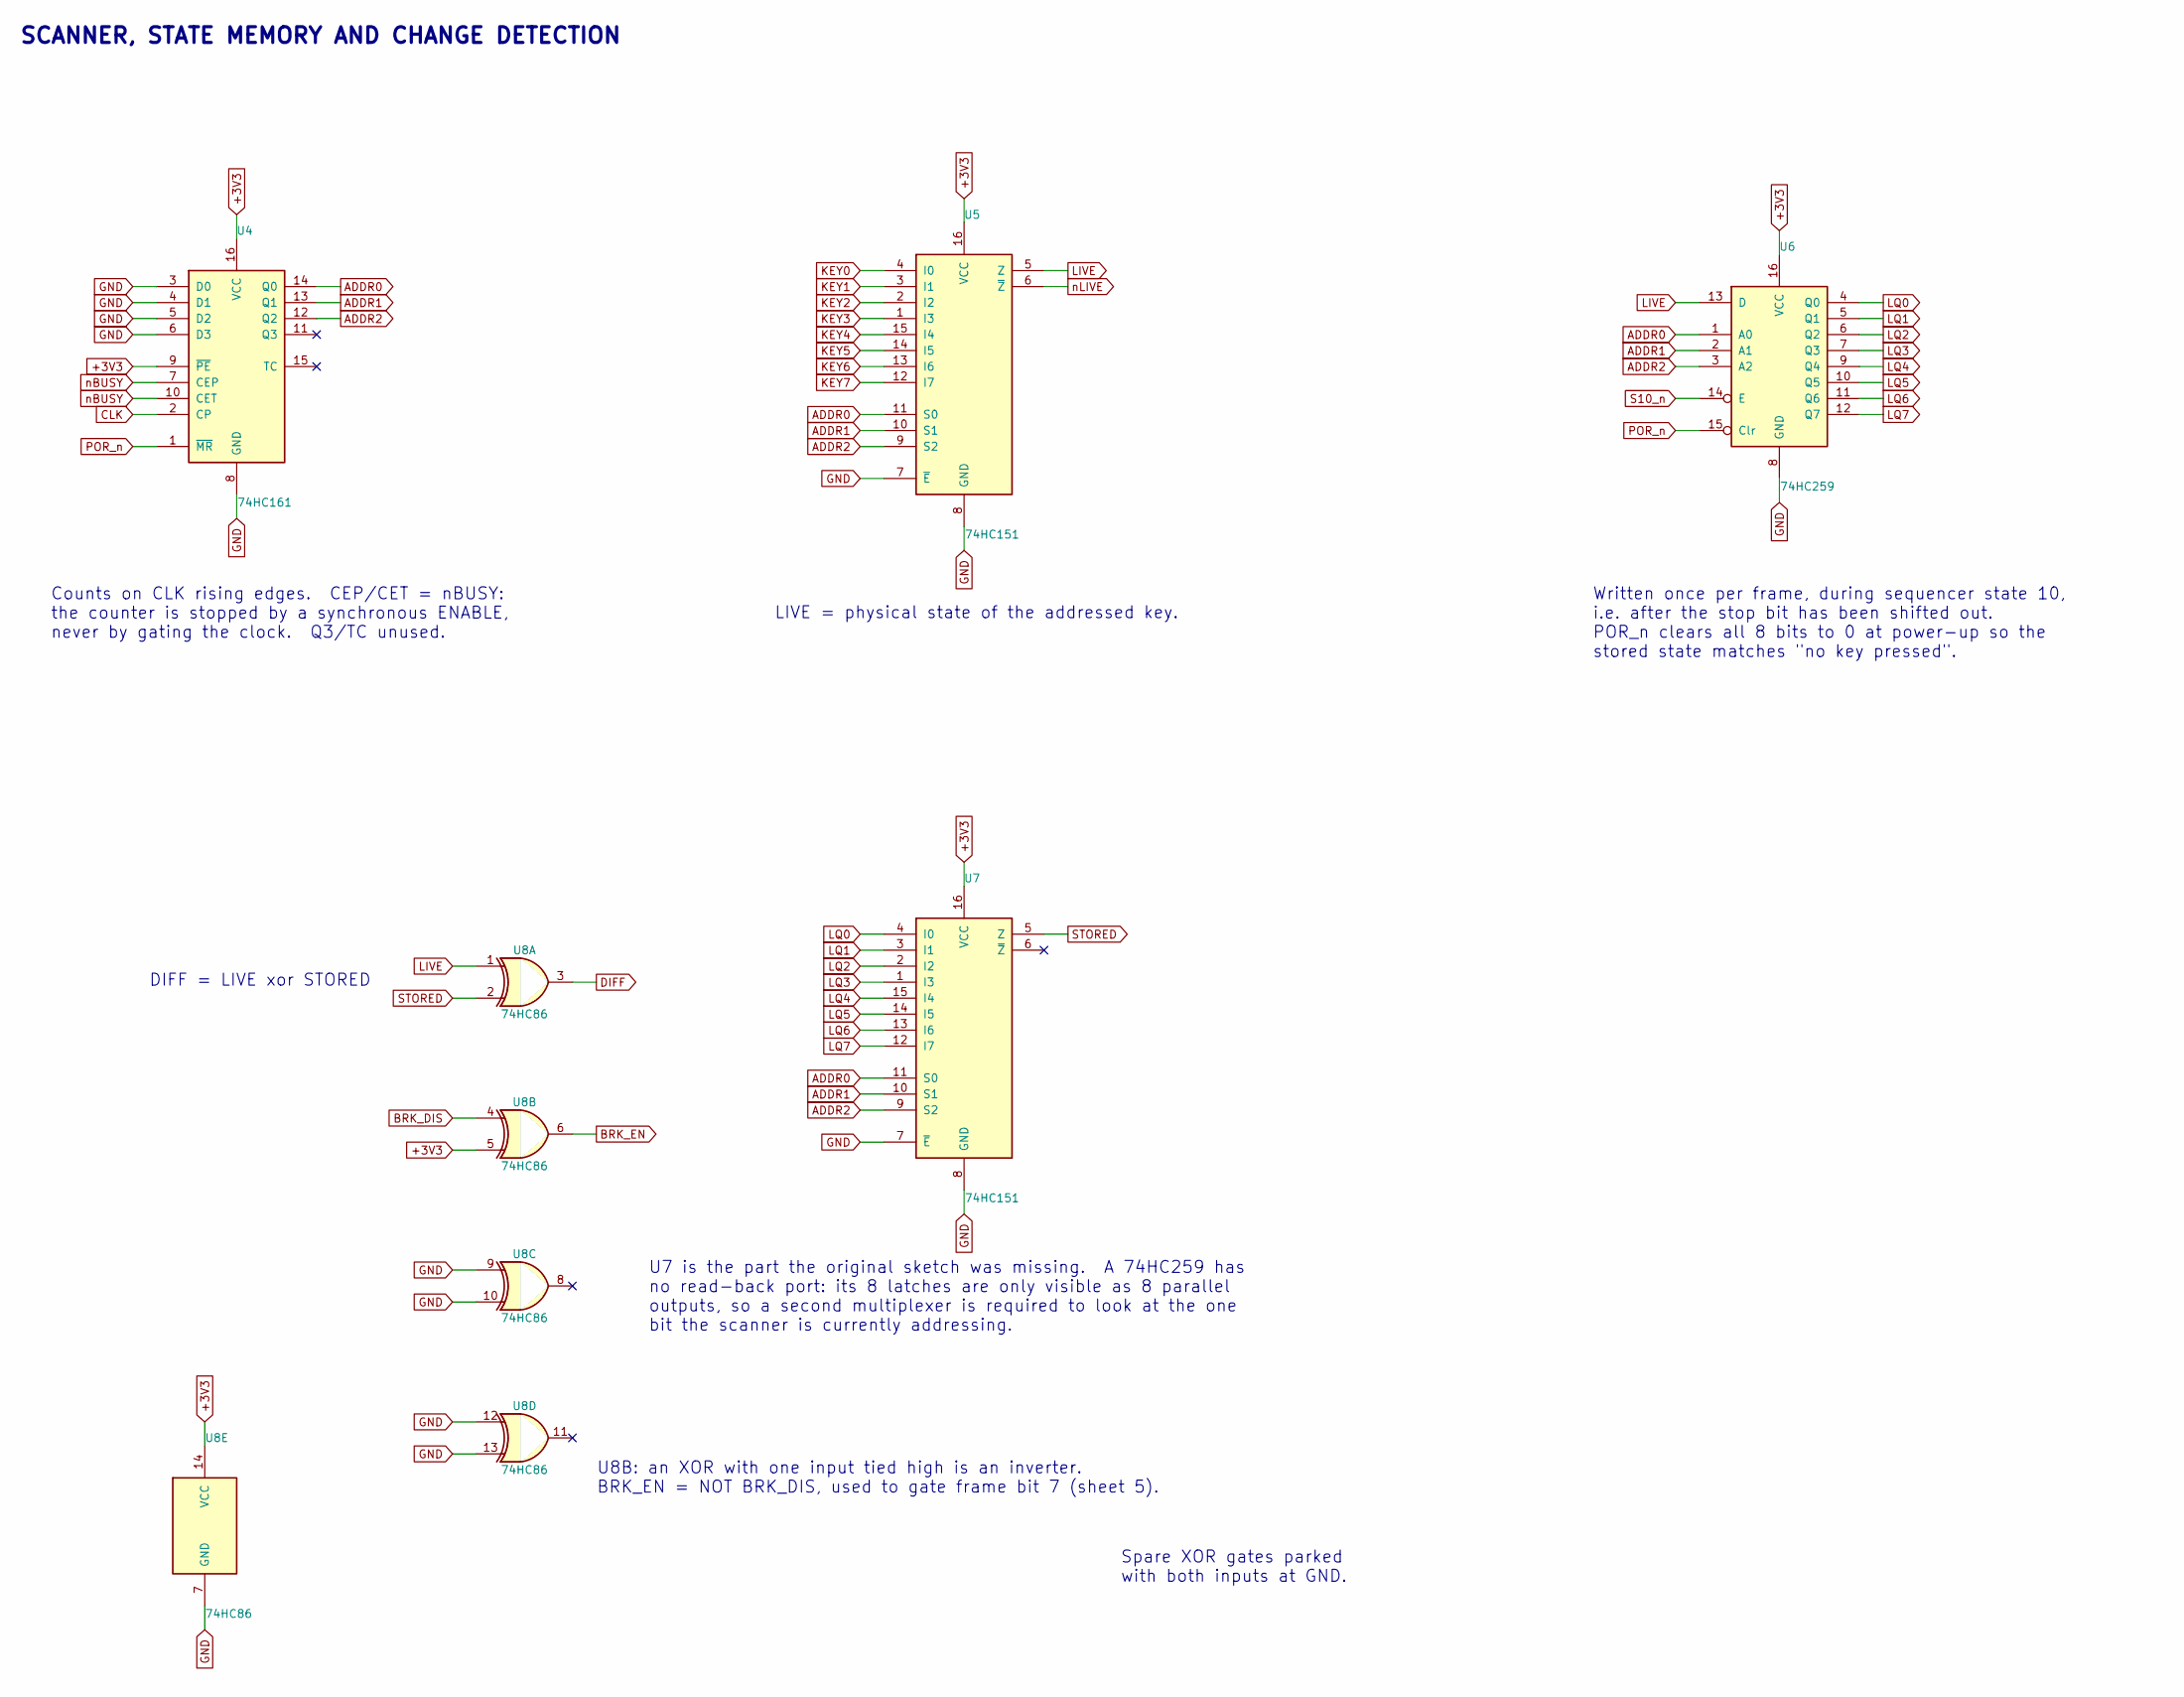
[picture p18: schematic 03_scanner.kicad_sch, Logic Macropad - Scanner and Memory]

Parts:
U4: 74HC161; SOIC-16_3.9x9.9mm_P1.27mm; MPN 74HC161D
U5, U7: 74HC151; SOIC-16_3.9x9.9mm_P1.27mm; MPN 74HC151D
U6: 74HC259; SOIC-16_3.9x9.9mm_P1.27mm; MPN 74HC259D
U8: 74HC86; SOIC-14_3.9x8.7mm_P1.27mm; MPN 74HC86D

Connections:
+3V3: U4.9 (~PE), U4.16 (VCC), U5.16 (VCC), U6.16 (VCC), U7.16 (VCC), U8.5, U8.14 (VCC); also elsewhere on the board
ADDR0: U4.14 (Q0), U5.11 (S0), U6.1 (A0), U7.11 (S0); also elsewhere on the board
ADDR1: U4.13 (Q1), U5.10 (S1), U6.2 (A1), U7.10 (S1); also elsewhere on the board
ADDR2: U4.12 (Q2), U5.9 (S2), U6.3 (A2), U7.9 (S2); also elsewhere on the board
BRK_DIS: U8.4; also elsewhere on the board
BRK_EN: U8.6; also elsewhere on the board
CLK: U4.2 (CP); also elsewhere on the board
DIFF: U8.3; also elsewhere on the board
GND: U4.3 (D0), U4.4 (D1), U4.5 (D2), U4.6 (D3), U4.8 (GND), U5.7 (~E), U5.8 (GND), U6.8 (GND), U7.7 (~E), U7.8 (GND), U8.7 (GND), U8.9, U8.10, U8.12, U8.13; also elsewhere on the board
KEY0: U5.4 (I0); also elsewhere on the board
KEY1: U5.3 (I1); also elsewhere on the board
KEY2: U5.2 (I2); also elsewhere on the board
KEY3: U5.1 (I3); also elsewhere on the board
KEY4: U5.15 (I4); also elsewhere on the board
KEY5: U5.14 (I5); also elsewhere on the board
KEY6: U5.13 (I6); also elsewhere on the board
KEY7: U5.12 (I7); also elsewhere on the board
LIVE: U5.5 (Z), U6.13 (D), U8.1; also elsewhere on the board
LQ0: U6.4 (Q0), U7.4 (I0)
LQ1: U6.5 (Q1), U7.3 (I1)
LQ2: U6.6 (Q2), U7.2 (I2)
LQ3: U6.7 (Q3), U7.1 (I3)
LQ4: U6.9 (Q4), U7.15 (I4)
LQ5: U6.10 (Q5), U7.14 (I5)
LQ6: U6.11 (Q6), U7.13 (I6)
LQ7: U6.12 (Q7), U7.12 (I7)
POR_n: U4.1 (~MR), U6.15 (Clr); also elsewhere on the board
S10_n: U6.14 (E); also elsewhere on the board
STORED: U7.5 (Z), U8.2
nBUSY: U4.7 (CEP), U4.10 (CET); also elsewhere on the board
nLIVE: U5.6 (~Z); also elsewhere on the board

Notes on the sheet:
LIVE = physical state of the addressed key.
DIFF = LIVE xor STORED
Spare XOR gates parked with both inputs at GND.
Counts on CLK rising edges. CEP/CET = nBUSY: the counter is stopped by a synchronous ENABLE, never by gating the clock. Q3/TC unused.
U8B: an XOR with one input tied high is an inverter. BRK_EN = NOT BRK_DIS, used to gate frame bit 7 (sheet 5).
SCANNER, STATE MEMORY AND CHANGE DETECTION
U7 is the part the original sketch was missing. A 74HC259 has no read-back port: its 8 latches are only visible as 8 parallel outputs, so a second multiplexer is required to look at the one bit the scanner is currently addressing.
Written once per frame, during sequencer state 10, i.e. after the stop bit has been shifted out. POR_n clears all 8 bits to 0 at power-up so the stored state matches "no key pressed".

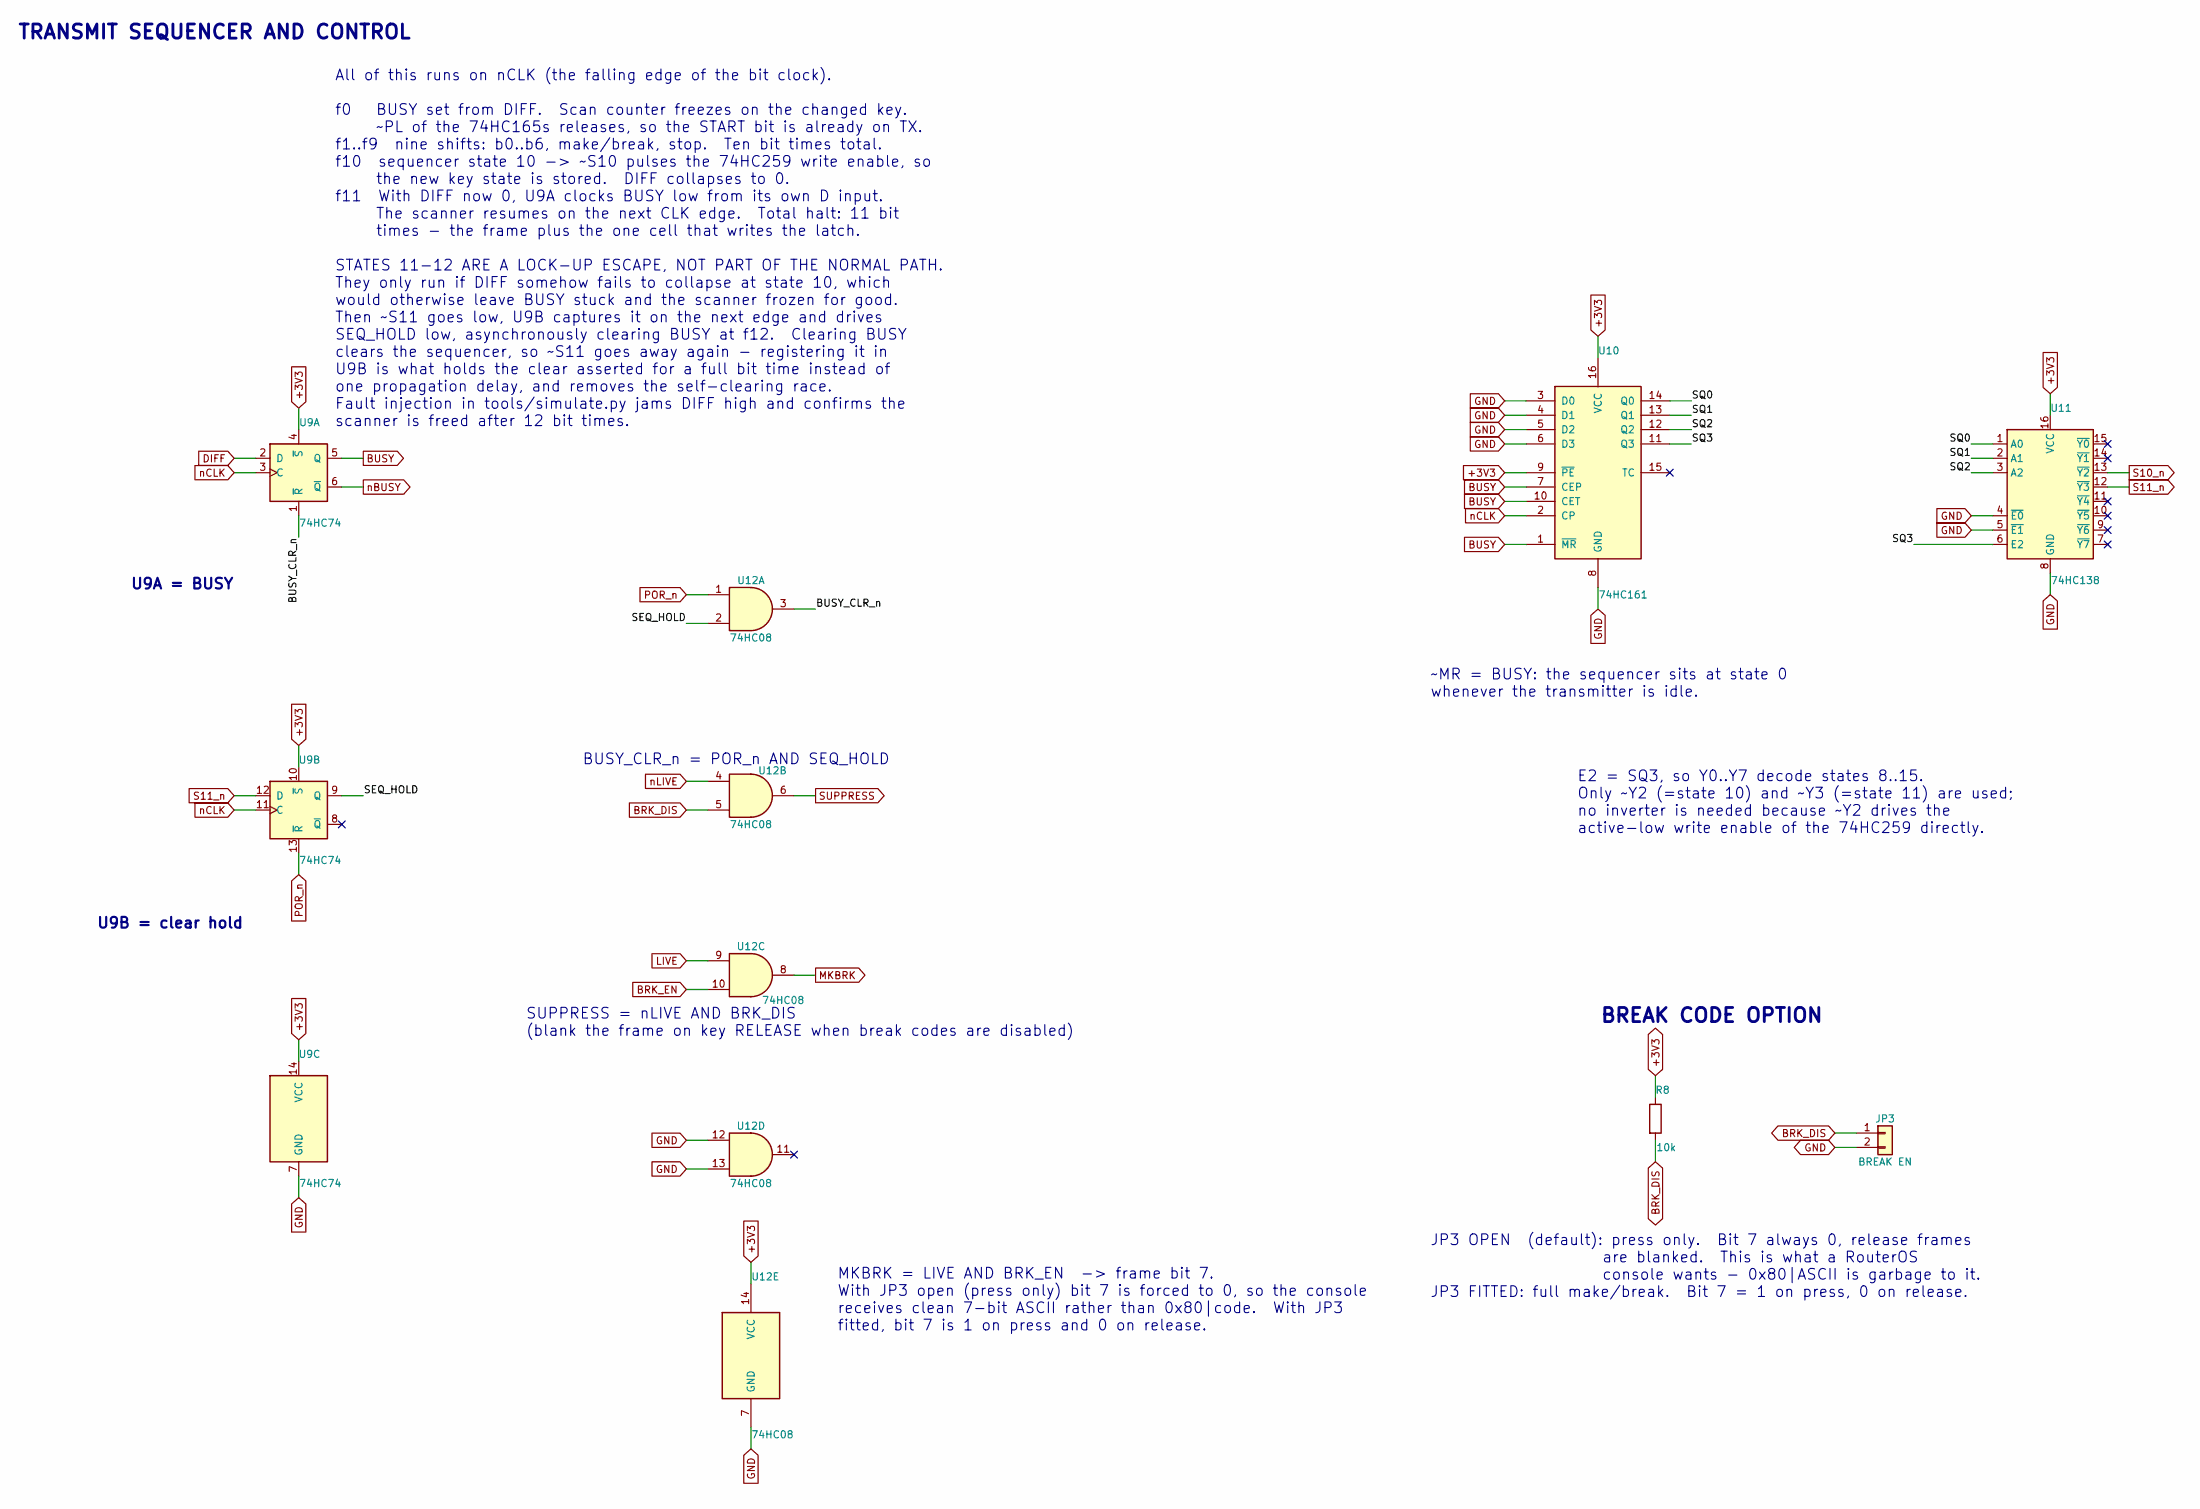
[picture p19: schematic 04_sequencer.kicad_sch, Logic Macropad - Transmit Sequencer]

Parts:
JP3: BREAK EN; PinHeader_1x02_P2.54mm_Vertical; MPN 2.54-1*40P
R8: 10k; R_0603_1608Metric
U9: 74HC74; SOIC-14_3.9x8.7mm_P1.27mm; MPN 74HC74D
U10: 74HC161; SOIC-16_3.9x9.9mm_P1.27mm; MPN 74HC161D
U11: 74HC138; SOIC-16_3.9x9.9mm_P1.27mm; MPN 74HC138D
U12: 74HC08; SOIC-14_3.9x8.7mm_P1.27mm; MPN 74HC08D

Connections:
+3V3: R8.1, U9.4 (~S), U9.10 (~S), U9.14 (VCC), U10.9 (~PE), U10.16 (VCC), U11.16 (VCC), U12.14 (VCC); also elsewhere on the board
/Transmit Sequencer/BUSY_CLR_n: U9.1 (~R), U12.3
/Transmit Sequencer/SEQ_HOLD: U9.9 (Q), U12.2
/Transmit Sequencer/SQ0: U10.14 (Q0), U11.1 (A0)
/Transmit Sequencer/SQ1: U10.13 (Q1), U11.2 (A1)
/Transmit Sequencer/SQ2: U10.12 (Q2), U11.3 (A2)
/Transmit Sequencer/SQ3: U10.11 (Q3), U11.6 (E2)
BRK_DIS: JP3.1, R8.2, U12.5; also elsewhere on the board
BRK_EN: U12.10; also elsewhere on the board
BUSY: U9.5 (Q), U10.1 (~MR), U10.7 (CEP), U10.10 (CET); also elsewhere on the board
DIFF: U9.2 (D); also elsewhere on the board
GND: JP3.2, U9.7 (GND), U10.3 (D0), U10.4 (D1), U10.5 (D2), U10.6 (D3), U10.8 (GND), U11.4 (~E0), U11.5 (~E1), U11.8 (GND), U12.7 (GND), U12.12, U12.13; also elsewhere on the board
LIVE: U12.9; also elsewhere on the board
MKBRK: U12.8; also elsewhere on the board
POR_n: U9.13 (~R), U12.1; also elsewhere on the board
S10_n: U11.13 (~Y2); also elsewhere on the board
S11_n: U9.12 (D), U11.12 (~Y3)
SUPPRESS: U12.6; also elsewhere on the board
nBUSY: U9.6 (~Q); also elsewhere on the board
nCLK: U9.3 (C), U9.11 (C), U10.2 (CP); also elsewhere on the board
nLIVE: U12.4; also elsewhere on the board

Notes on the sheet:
BREAK CODE OPTION
~MR = BUSY: the sequencer sits at state 0 whenever the transmitter is idle.
MKBRK = LIVE AND BRK_EN -> frame bit 7. With JP3 open (press only) bit 7 is forced to 0, so the console receives clean 7-bit ASCII rather than 0x80|code. With JP3 fitted, bit 7 is 1 on press and 0 on release.
All of this runs on nCLK (the falling edge of the bit clock). f0 BUSY set from DIFF. Scan counter freezes on the changed key. ~PL of the 74HC165s releases, so the START bit is already on TX. f1..f9 nine shifts: b0..b6, make/break, stop. Ten bit times total. f10 sequencer state 10 -> ~S10 pulses the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
SUPPRESS = nLIVE AND BRK_DIS (blank the frame on key RELEASE when break codes are disabled)
TRANSMIT SEQUENCER AND CONTROL
JP3 OPEN (default): press only. Bit 7 always 0, release frames are blanked. This is what a RouterOS console wants - 0x80|ASCII is garbage to it. JP3 FITTED: full make/break. Bit 7 = 1 on press, 0 on release.
U9B = clear hold
U9A = BUSY
BUSY_CLR_n = POR_n AND SEQ_HOLD
E2 = SQ3, so Y0..Y7 decode states 8..15. Only ~Y2 (=state 10) and ~Y3 (=state 11) are used; no inverter is needed because ~Y2 drives the active-low write enable of the 74HC259 directly.

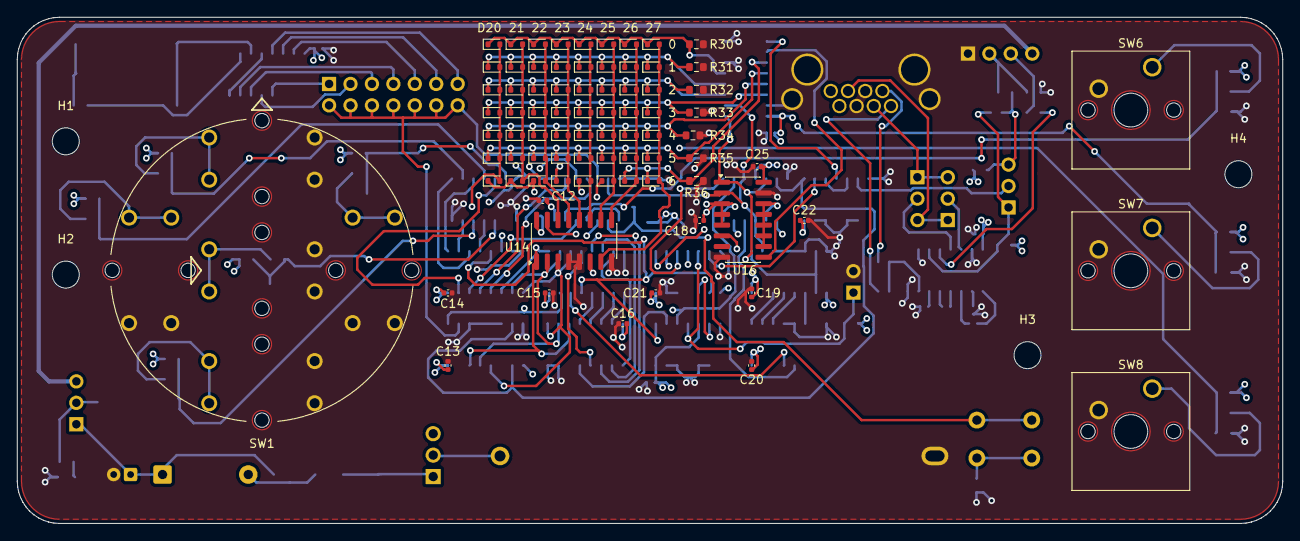
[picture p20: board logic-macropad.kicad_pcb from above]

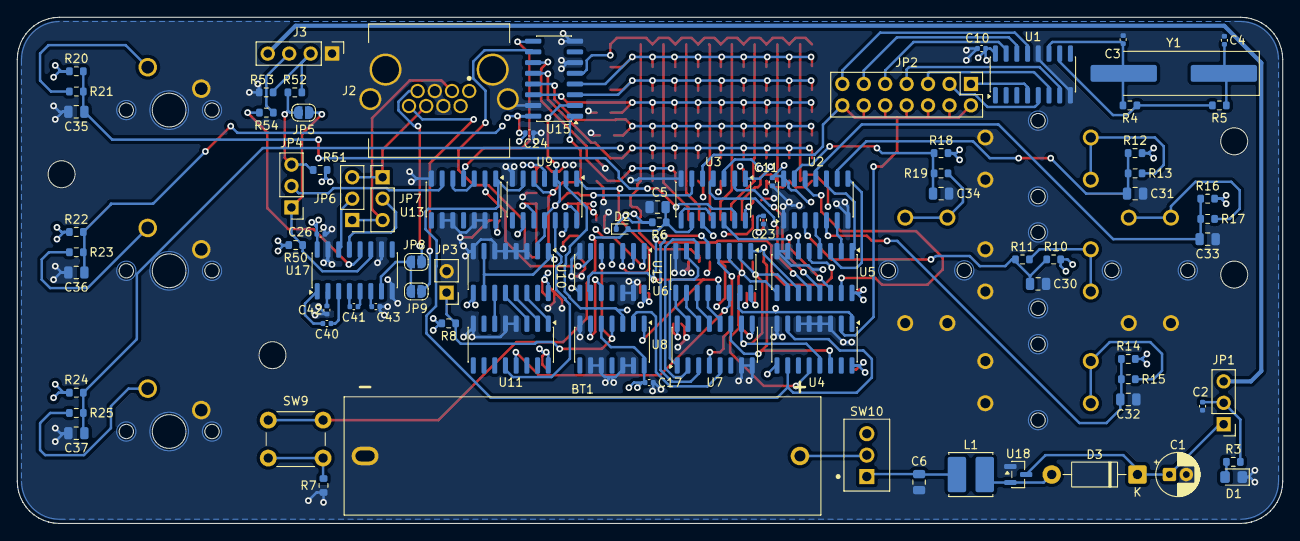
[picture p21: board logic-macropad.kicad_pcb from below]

Board: 6 copper layers, 150.0 x 60.0 mm, 170 parts (86 on the bottom side), 114 nets.

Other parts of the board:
H1, H2, H3, H4: M3; MountingHole_3.2mm_M3
